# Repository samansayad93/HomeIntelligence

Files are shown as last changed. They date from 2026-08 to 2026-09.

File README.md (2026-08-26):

# intelligence — ESP32 Home Intelligence Hub

A Wi-Fi-connected, MQTT-integrated home automation and sensing node for the
**ESP32** (Arduino framework via PlatformIO). It reads a set of environmental
sensors, publishes them over MQTT, and can **capture and replay RF (433 & 315 MHz)
and infrared signals** — turning the board into a bridge between physical remotes,
sensors, and your smart-home broker.

On first boot it opens a captive setup portal, so no Wi-Fi or MQTT credentials are
hard-coded into the firmware.

---

## Table of Contents

- [Features](#features)
- [Hardware](#hardware)
- [Wiring](#wiring)
- [Software Architecture](#software-architecture)
- [Project Structure](#project-structure)
- [Getting Started](#getting-started)
- [First-Boot Provisioning](#first-boot-provisioning)
- [Configuration](#configuration)
- [Usage](#usage)
  - [Serial & MQTT Commands](#serial--mqtt-commands)
  - [MQTT Topics](#mqtt-topics)
- [Web Dashboard](#web-dashboard)
- [RF — Dual Band (433 & 315 MHz)](#rf--dual-band-433--315-mhz)
- [Persistent Storage](#persistent-storage)
- [Dependencies](#dependencies)
- [Known Issues & To-Do](#known-issues--to-do)

---

## Features

- **Provisioning portal** — configure Wi-Fi + MQTT from a phone/laptop on first
  boot; no rebuild required to change networks. The board runs in `WIFI_AP_STA`,
  so the `Intelligence-Setup` AP stays **always on** — you can connect to it at any
  time, even while the board is correctly joined to your router, and change the
  broker or Wi-Fi AP without erasing flash (see
  [First-Boot Provisioning](#first-boot-provisioning)).
- **MQTT telemetry** — publishes light, temperature, humidity, gas, and motion
  readings on a configurable base topic.
- **MQTT control** — the same commands available over Serial are accepted over an
  MQTT command topic.
- **Web dashboard** — a server-less browser dashboard (in [`Website/`](Website/))
  connects directly to the broker over WebSocket to show live telemetry and send
  the same commands (see [Web Dashboard](#web-dashboard)).
- **RF capture & replay** — record 433 *or* 315 MHz signals by name and replay
  them later. Both bands are handled simultaneously (see
  [RF — Dual Band](#rf--dual-band-433--315-mhz)).
- **IR capture & replay** — record infrared signals (NEC / SONY / SAMSUNG or raw)
  and replay them.
- **Local persistence** — all saved RF/IR signals and the provisioning profile are
  stored in LittleFS and survive reboots.
- **Status LED** — a heartbeat LED blinks (1 s on / 5 s off) while the firmware is
  running and gives a short 500 ms pulse whenever an RF/IR signal is captured or
  transmitted, giving at-a-glance feedback that the board is alive and acting.
- **Built-in alarm** — a buzzer that can be triggered manually, by gas threshold,
  or by motion.

## Hardware

**Board:** ESP32 DevKit (any common 38-pin variant). The full schematic and PCB
layout are checked into [`hardware/`](hardware/) (`Main.SchDoc` / `Main.pdf`
schematic, `PCB1.PcbDoc` board).

| Part | Purpose |
|---|---|
| DHT11 | Temperature & humidity |
| LDR (photoresistor) | Ambient light level |
| MQ-2 | Combustible gas / smoke |
| HC-SR505 (PIR) | Motion detection |
| Active buzzer | Alarm |
| Status LED | Heartbeat + capture/transmit pulse |
| 433 MHz TX + RX pair (e.g. FS1000A / XY-MK-5V) | 433 MHz RF |
| 315 MHz TX + RX pair | 315 MHz RF |
| IR receiver (e.g. TSOP38238) + IR LED | Infrared capture & transmit |

> The ESP32's ADC1 input-only pins (GPIO 34/35) are used for the analog sensors.

## Wiring

| Device | ESP32 GPIO | Notes |
|---|---|---|
| DHT11 data | **33** | 10 kΩ pull-up recommended |
| LDR (analog) | **34** | Input-only ADC1 pin |
| MQ-2 (analog AO) | **35** | Input-only ADC1 pin |
| PIR OUT | **13** | |
| Buzzer (+) | **32** | Active-low drive (LOW = on) |
| Status LED | **39** | Heartbeat + capture/transmit pulse |
| IR receiver DATA | **14** | |
| IR LED (transmit) | **25** | |
| 433 MHz RX DATA | **27** | |
| 433 MHz TX DATA | **26** | |
| 315 MHz RX DATA | **4** | *Adjustable — see config* |
| 315 MHz TX DATA | **5** | *Adjustable — see config* |

All modules share the ESP32's 3.3 V / 5 V and GND. Note that most 433/315 and IR
transmitter/receiver boards run at **5 V**; power them from `VCC` (5 V), and level-
shift the TX *data* lines (GPIO 26 / 5 / 25) if your module is not 5 V-tolerant.
Receiver DATA lines are safe to read directly.

---

## Software Architecture

The firmware is organized into independent modules, each with a header in
`include/<Module>/` and an implementation in `src/<Module>/`. A single `Sensors`
module orchestrates the others from `loop()`.

| Module | Responsibility |
|---|---|
| `main` | Setup/loop entry; routes MQTT commands to the serial handler |
| `Sensors` | Periodic sensor reads, RF/IR receive polling, alarm ticking |
| `Provisioning` | Always-on `WIFI_AP_STA` soft AP (`Intelligence-Setup`) + DNS hijack + web form to capture/change Wi-Fi/MQTT/device creds; reachable at any time, even while joined to the router |
| `MQTT` | Wi-Fi STA connect, PubSubClient connect/reconnect, publish/subscribe |
| `Serial` | Text command parser (shared by Serial and MQTT) + `help` |
| `RF` | Dual-band (433/315) RF capture & replay via RCSwitch |
| `IR` | Infrared capture & replay via IRremoteESP8266 |
| `Alarm` | Buzzer on/off + 2 s duty-cycle while alarming (active-low) |
| `LED` | Status LED heartbeat + capture/transmit pulse |
| `DHT`, `LDR`, `MQ2`, `PIR` | Individual sensor drivers |
| `Memory` | LittleFS JSON load/save for RF, IR, and provisioning data |
| `config` | Central pin map, MQTT topics, timing constants |

### Runtime loop

`setup()` → begins Serial → loads the saved provisioning profile → starts the
always-on config AP (`WIFI_AP_STA`) → sets up sensors + MQTT → prints help.

`loop()` → `handleSerial()` → `handleMQTT()` → `handleConfigAP()` → `handleSensors()`.

The board runs in `WIFI_AP_STA`: the station joins the provisioned router for MQTT
telemetry, while the `Intelligence-Setup` soft AP keeps broadcasting so the config
portal at `http://192.168.4.1` is reachable at any time — first boot or fully
provisioned and online alike. If Wi-Fi won't join, the station link is simply
retried; the AP (and thus re-provisioning) is always available regardless. A
broker-only outage (Wi-Fi up, broker down) does **not** affect the AP — it just keeps
retrying MQTT.

`handleSensors()` polls for an in-progress RF/IR capture, ticks the alarm buzzer,
ticks the status LED (heartbeat + any capture/transmit pulse), optionally checks
PIR motion, and every 10 s prints and publishes the sensor suite (LDR, temp,
humidity, PIR). MQ-2 is read on its own 10 s cadence after a 5 min warm-up.

## Project Structure

```
.
├── platformio.ini          # Build config, library deps, LittleFS filesystem
├── config.h (include/)     # Pins, topics, intervals (single source of truth)
├── include/                # Headers per module
│   └── <Module>/*.h
├── src/
│   ├── main.cpp
│   └── <Module>/*.cpp
├── lib/                    # (project-local libraries, currently empty)
├── hardware/               # Schematic (Main.SchDoc / Main.pdf) + PCB (PCB1.PcbDoc)
├── Website/                # Server-less browser dashboard (MQTT over WebSocket)
├── test/
└── note.md                 # Developer to-do / known-bugs scratchpad
```

---

## Getting Started

1. **Install PlatformIO**

   ```bash
   python -m pip install platformio
   ```

   (Or use the PlatformIO IDE extension for VS Code.)

2. **Build**

   ```bash
   pio run
   ```

3. **Upload to the board**

   ```bash
   pio run -t upload
   ```

4. **Open the serial monitor** (115200 baud)

   ```bash
   pio device monitor
   ```

> LittleFS is created/formatted automatically on first run — there is no `data/`
> folder to upload. The provisioning and signal files are written at runtime.

## First-Boot Provisioning

The board always boots in `WIFI_AP_STA` — it joins your router as a station (for
MQTT) **and** continuously broadcasts a setup access point:

| | |
|---|---|
| **SSID** | `Intelligence-Setup` |
| **Password** | `12345678` |
| **Setup URL** | `http://192.168.4.1` |

The AP runs a **captive portal**: it hijacks DNS and intercepts the OS
connectivity-check probes (iOS, Android, Windows), so connecting to the AP usually
pops the setup page automatically.

1. Connect to the `Intelligence-Setup` Wi-Fi network (the portal may open on its
   own).
2. Open `http://192.168.4.1` in a browser if it did not.
3. Fill in your Wi-Fi SSID/password, MQTT broker host/port (and optional user/
   pass), and a **Device** name. The device name becomes the per-device segment of
   every MQTT topic (see [MQTT Topics](#mqtt-topics)), so give each board a unique
   one. Then **Save & Restart**.
4. The board reboots, joins your Wi-Fi, and connects to the broker.

If no provisioning profile exists, the firmware falls back to the `WIFI_SSID` /
`MQTT_HOST` constants in `config.h` for the station link. To re-provision, you do
not need to erase flash or trigger a failure — see below.

### Re-provisioning while connected (always-on config AP)

The `Intelligence-Setup` AP stays **up even while the board is correctly joined to
your router**, so you can change the **MQTT broker** or the **Wi-Fi AP** at any time
without erasing flash, dropping the station link on purpose, or waiting for a
failure:

1. From any phone/laptop, connect to the `Intelligence-Setup` Wi-Fi network
   (`12345678`).
2. Open `http://192.168.4.1` in a browser (the captive portal may open on its own).
3. The form is **prefilled** with the current SSID, broker host/port, username,
   and device name, so you can edit just the field you want to change. Password
   fields are left blank on purpose (they are not echoed back); **leave them blank
   to keep the current password**, or type a new one to replace it.
4. **Save & Restart** — the board writes the new profile and reboots into it.

Because the board keeps its station link up during normal operation, you can also
still reach it over your normal LAN at its station IP for MQTT/dashboard traffic;
only configuration changes go through the `Intelligence-Setup` AP.

## Configuration

All tunables live in [`include/config.h`](include/config.h):

- **Pins** — the wiring table above.
- **MQTT** — `MQTT_BASE_TOPIC` (`homeintelligence`), broker host/port, client ID
  (`esp32-intelligence`, used as the per-device topic segment when no device name is
  provisioned), credentials (used only as a fallback; the portal overrides them).
- **Timing** — sensor interval (10 s), MQ-2 preheat (5 min), MQ-2 threshold (700),
  buzzer duty cycle (2 s), MQTT reconnect interval (1 s), status LED heartbeat
  (1 s on / 5 s off, 500 ms pulse).

---

## Usage

The same text commands work two ways:
- typed into the **Serial monitor** at 115200, or
- published to the **MQTT command topic** `<base>/<device>/command`, e.g.
  `homeintelligence/esp32-intelligence/command` (see [MQTT Topics](#mqtt-topics)).

### Serial & MQTT Commands

| Command | Action |
|---|---|
| `rf rx <name>` | Wait for an RF signal (433 **or** 315) and save it as `<name>` |
| `rf tx <name>` | Transmit the RF signal saved as `<name>` (on its original band) |
| `rf list` | List saved RF signals (name, band, code, bits, protocol, pulse) — printed to Serial **and** published to `…/RF/list` |
| `rf del <name>` | Delete the RF signal saved as `<name>` |
| `ir rx <name>` | Wait for an IR signal and save it as `<name>` |
| `ir tx <name>` | Transmit the IR signal saved as `<name>` |
| `ir list` | List saved IR signals — printed to Serial **and** published to `…/IR/list` |
| `ir del <name>` | Delete the IR signal saved as `<name>` |
| `buzzer on` / `buzzer off` | Start / stop the alarm buzzer |
| `motion on` / `motion off` | Start / stop the motion detection |
| `help` | Print the command list |

**Examples**

```
rf rx living_room_light      # press your 433/315 remote; it's captured + saved
rf tx living_room_light      # replay it later (correct band chosen automatically)
ir rx tv_power
ir tx tv_power
rf del living_room_light   # remove a saved RF signal
buzzer off
```

### MQTT Topics

All topics are namespaced per device: `<base>/<device>/<subtopic>`, where `<base>`
is `MQTT_BASE_TOPIC` (`homeintelligence`) and `<device>` is the name set in the
provisioning portal (or `MQTT_CLIENT_ID`, `esp32-intelligence`, as a fallback). The
examples below use `homeintelligence/esp32-intelligence`.

Published to:

| Topic | Payload | Trigger |
|---|---|---|
| `…/sensor/LDR` | light reading | every 10 s |
| `…/sensor/TEMP` | °C | every 10 s |
| `…/sensor/HUM` | % humidity | every 10 s |
| `…/sensor/PIR` | `0`/`1` | every 10 s |
| `…/sensor/MQ2` | gas reading | every 10 s (after warm-up) |
| `…/alarm` | `MQ2 threshold exceeded!` / `Motion Detected!` | when an incident occurs (also starts the buzzer) |
| `…/alarm` | `Motion Detection: ON` / `Motion Detection: OFF` | when motion detection is armed/disarmed (retained) |
| `…/RF/list` | JSON per saved RF signal (`name`, `code`, `bits`, `protocol`, `pulse`, `band`) | on `rf list` |
| `…/IR/list` | JSON per saved IR signal (`name`, `protocol`, `value`, `bits`) | on `ir list` |

(`…` = `homeintelligence/<device>`.)

Subscribed to:

| Topic | Payload |
|---|---|
| `…/command` | any command from the table above |

So to toggle the buzzer from your broker, publish `buzzer on` to
`homeintelligence/esp32-intelligence/command`.

---

## Web Dashboard

A self-contained, server-less dashboard lives in [`Website/`](Website/). It connects
**directly from the browser to your MQTT broker over WebSocket** (no backend, no
build step) to render live sensor cards with sparklines, an alarm banner, and a set
of control buttons that publish the same commands as Serial.

```
┌────────────┐   WebSocket (ws/wss)   ┌──────────────┐   TCP 1883   ┌────────────┐
│  Browser   │ ─────────────────────▶ │  MQTT broker │ ───────────▶ │   ESP32    │
│  dashboard │ ◀───────────────────── │  (Mosquitto) │ ◀─────────── │  (firmware)│
└────────────┘   sensor/+alarm  (sub) └──────────────┘  command (pub)└────────────┘
```

Because browsers cannot speak raw MQTT/TCP, your broker must expose a **WebSocket
listener** (e.g. Mosquitto `listener 9001` + `protocol websockets`). The dashboard
subscribes to `<base>/<device>/sensor/#` and `<base>/<device>/alarm`, and publishes
to `<base>/<device>/command` — set the same `<device>` you provisioned.

Quick start:

```bash
cd Website
python3 -m http.server 8080      # then open http://localhost:8080
```

Full setup, options, and troubleshooting are in [`Website/README.md`](Website/README.md).

---

## RF — Dual Band (433 & 315 MHz)

RF supports **both 433 MHz and 315 MHz simultaneously**. Because a receiver module
is frequency-specific (a 433 module cannot decode a 315 MHz signal and vice-versa),
the firmware drives **two independent `RCSwitch` instances** — one per band — each
on its own RX/TX pin pair:

| Band | RX pin | TX pin |
|---|---|---|
| 433 MHz | GPIO 27 | GPIO 26 |
| 315 MHz | GPIO 4 | GPIO 5 |

- **Capture:** `rf rx <name>` listens on *both* receivers; whichever band actually
  receives the signal is recorded. The console confirms the band, e.g.
  `Saved RF signal: living_room_light (433 MHz)`.
- **Replay:** `rf tx <name>` automatically uses the band that signal was captured
  on — no need to specify it.

Each saved signal stores `code`, `bits`, `protocol`, `pulse`, and `band`, so it is
always replayed faithfully on the right hardware. If the default 315 pins (4/5)
clash with your board, change `RF_RX_315_PIN` / `RF_TX_315_PIN` in
[`config.h`](include/config.h).

---

## Persistent Storage

LittleFS holds three JSON files (created on demand):

| File | Contents |
|---|---|
| `/provisioning.json` | Wi-Fi + MQTT credentials from the portal |
| `/rf_signals.json` | Saved RF signals (up to 20) |
| `/ir_signals.json` | Saved IR signals (up to 20, raw buffer up to 200 samples) |

Old RF captures saved before dual-band support are loaded with a default band of
**433 MHz**, so existing recordings keep working.

## Dependencies

Declared in [`platformio.ini`](platformio.ini):

- `adafruit/DHT sensor library` + `adafruit/Adafruit Unified Sensor` — DHT11
- `sui77/rc-switch` — 433/315 MHz RF
- `crankyoldgit/IRremoteESP8266` — IR send/receive
- `bblanchon/ArduinoJson` — JSON config & signal storage
- `knolleary/PubSubClient` — MQTT client

PlatformIO installs these automatically on first build.

---

## Known Issues & To-Do

Tracked in [`note.md`](note.md):

- **IR TX does not currently work** (RX is functional).
- Make the web dashboard multi-page.

---

*No license has been set for this project. Add one before sharing or deploying.*

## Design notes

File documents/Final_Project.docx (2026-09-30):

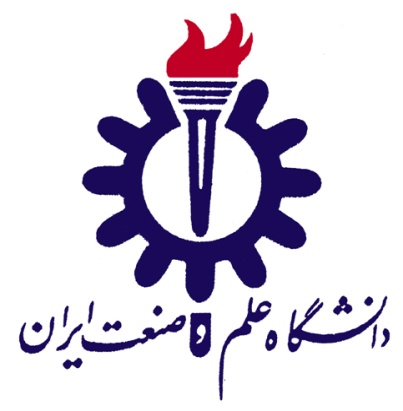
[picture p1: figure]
IUST

دانشكده مهندسی کامپیوتر

پروژه پایانی کارشناسی

عنوان پروژه:

طراحی و پیاده سازی سامانه هوشمند تشخیص دود و کنترل تجهیزات خانگی مبتی بر ESP32

نگارنده:

سامان صیاد فعال

۴۰۱۵۲۱۴۰۸

استاد راهنما:

دكتر امیر مهدی حسینی منزه

شهریور ماه ۱۴۰۵

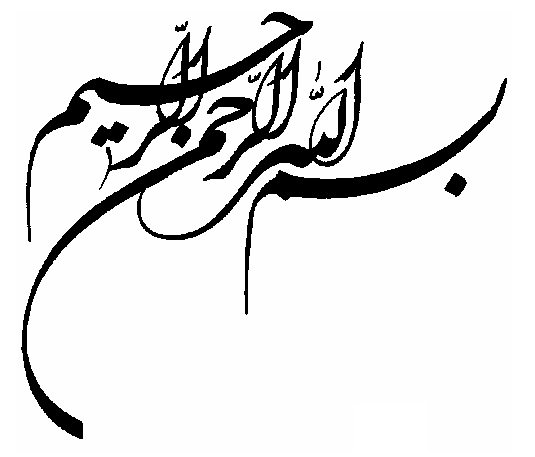
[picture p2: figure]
␂矸曰矷淀矵ح矨

چکيده

در این پروژه، یک سامانه هوشمند مبتنی بر برد ESP32 با هدف طراحی و پیاده سازی یک واحد یکپارچه برای پایش شرایط محیطی، تشخیص شرایط خطر و کنترل تجهیزات الکترونیکی توسعه داده شده است. هدف اصلی سامانه، فراهم کردن امکان دریافت و پردازش اطلاعات محیطی و انتقال آنها به یک سامانه نرم افزاری از طریق شبکه بی‌سیم، در کنار ایجاد قابلیت کنترل و ارسال فرمان به برخی تجهیزات الکترونیکی موجود در محیط است. به منظور پایش وضعیت محیط، دستگاه به مجموعه ای از حسگرها شامل حسگر گاز MQ-2، حسگر دما و رطوبت DHT11، حسگر شدت نور LDR و حسگر تشخیص حرکت PIR مجهز شده است. حسگر MQ-2 با استفاده از خروجی آنالوگ، امکان اندازه گیری سطح نسبی گاز و دود موجود در محیط را فراهم می کند و در صورت عبور مقدار اندازه گیری شده از آستانه تعیین شده، شرایط به عنوان وضعیت هشدار شناسایی شده و سامانه اقدام به فعال سازی هشدار صوتی می کند. همچنین اطلاعات مربوط به دما، رطوبت، شدت نور و وضعیت حرکت در بازه های زمانی مشخص از محیط دریافت شده و برای پایش و نمایش وضعیت سیستم در اختیار سامانه نرم افزاری قرار می گیرد. به منظور افزایش قابلیت کاربردی دستگاه در حوزه کنترل تجهیزات، دو بستر ارتباطی رادیویی RF در فرکانس های ۳۱۵ و ۴۳۳ مگاهرتز و همچنین ارتباط مادون قرمز IR در سامانه در نظر گرفته شده است. این بخش امکان دریافت و شناسایی فرمان های رادیویی و مادون قرمز، ذخیره سازی آنها و استفاده مجدد از فرمان های ذخیره شده برای کنترل تجهیزات سازگار را فراهم می کند. ارتباط دستگاه با شبکه از طریق قابلیت WiFi برد ESP32 برقرار شده و به منظور انتقال داده و فرمان میان دستگاه و سامانه نرم افزاری از پروتکل MQTT استفاده شده است. همچنین برای ساده سازی راه اندازی اولیه و جلوگیری از وابستگی به اطلاعات شبکه ثابت، یک سازوکار provisioning در دستگاه پیاده سازی شده است که از طریق یک نقطه دسترسی بی‌سیم و درگاه پیکربندی تحت وب، امکان تنظیم مشخصات شبکه WiFi، اطلاعات MQTT Broker را فراهم می کند. در بخش نرم افزاری کاربر نیز یک داشبورد تحت وب برای نمایش داده های دریافت شده از دستگاه و ارسال فرمان های کنترلی طراحی شده است. به این ترتیب، کاربر می تواند بدون نیاز به دسترسی مستقیم به سخت افزار، وضعیت محیط را پایش کرده، شرایط هشدار را مشاهده نموده و فرمان های مورد نیاز را برای تجهیزات ارسال کند. این سامانه می تواند به عنوان یک نمونه پایه برای توسعه راهکار های هوشمند سازی محیط های مسکونی و اداری، سامانه های پایش محیطی و سیستم های کنترل تجهیزات مورد استفاده قرار گیرد.

واژه‌هاي كليدي: خانه هوشمند، اتوماسیون خانگی، ESP32، اینترنت اشیا (IoT)

# فصل 1: مقدمه

در سال‌های اخیر، توسعه فناوری‌های ارتباطی و سامانه های نهفته موجب گسترش استفاده از سیستم‌های هوشمند در محیط‌های مسکونی، اداری و صنعتی شده است. یکی از مهم‌ترین حوزه‌های حاصل از این توسعه، اینترنت اشیا (Internet of Things یا IoT) است. اینترنت اشیا به شبکه ای از تجهیزات فیزیکی اطلاق می‌شود که با بهره‌گیری از حسگرها، پردازنده ها، نرم‌افزارها و واسط های ارتباطی، قابلیت جمع آوری، پردازش، تبادل اطلاعات و در برخی موارد اعمال کنترل بر محیط پیرامون خود را دارند [1].در چنین سامانه هایی، حسگرها وظیفه دریافت اطلاعات از محیط، واحد پردازشی وظیفه تحلیل و مدیریت داده ها و بخش ارتباطی وظیفه انتقال اطلاعات و دریافت فرمان های کنترلی را بر عهده دارد [1] [2].

یکی از کاربردهای مهم اینترنت اشیا، توسعه سامانه های هوشمند خانگی است. در یک محیط هوشمند، تجهیزات مختلف می‌توانند از طریق یک شبکه ارتباطی با یکدیگر و با کاربر تعامل داشته باشند. این تعامل می تواند شامل پایش شرایط محیطی، تشخیص رخداد های غیرعادی، ارسال هشدار، کنترل تجهیزات الکتریکی و ثبت اطلاعات باشد. استفاده از چنین سامانه هایی می تواند امکان نظارت از راه دور و کاهش وابستگی به کنترل دستی تجهیزات را فراهم کند.

در این پروژه، یک هاب هوشمند مبتنی بر برد ESP32 طراحی و پیاده سازی شده است. ESP32 یک سامانه روی تراشه با قابلیت WiFi در باند ۲.۴ گیگاهرتز، پردازنده ۳۲ بیتی و مجموعه‌ای از واسط های ورودی/خروجی دیجیتال و آنالوگ است که توسط شرکت Espressif ارائه شده و برای کاربردهایی از جمله تجهیزات هوشمند خانگی و اینترنت اشیا مناسب است [3]. این ویژگی ها باعث شده است ESP32 بتواند علاوه بر پردازش داده های حسگرها، ارتباط شبکه ای و کنترل تجهیزات جانبی را نیز در یک واحد سخت افزاری انجام دهد.

سیستم توسعه یافته در این پروژه علاوه بر تشخیص دود و گاز، امکان اندازه گیری دما، رطوبت و شدت نور و همچنین تشخیص حرکت را فراهم می‌کند. همچنین برای افزایش قابلیت کنترل تجهیزات مختلف، دو مجموعه ارتباط رادیویی در فرکانس های ۳۱۵ و ۴۳۳ مگاهرتز و یک مجموعه ارتباط مادون قرمز در نظر گرفته شده است. به این ترتیب، سیستم قادر است برخی سیگنال های رادیویی و مادون قرمز را دریافت، ذخیره و در صورت نیاز بازپخش کند.

ارتباط میان هاب هوشمند و زیرساخت نرم‌افزاری سیستم از طریق WiFi و پروتکل MQTT انجام می‌شود. MQTT یک پروتکل ارتباطی سبک مبتنی بر الگوی انتشار/اشتراک (Publish/Subscribe) است که به طور ویژه برای محیط‌های دارای محدودیت منابع و کاربردهای ماشین به ماشین و اینترنت اشیا مناسب طراحی شده است [4]. در این پروژه، داده های حسگرها از طریق MQTT منتشر شده و فرمان های کنترلی نیز از طریق همین بستر به ESP32 ارسال می‌شوند.

از سوی دیگر، برای تعامل کاربر با سیستم، یک داشبورد تحت وب طراحی شده است که از طریق WebSocket به MQTT Broker متصل می‌شود. این داشبورد امکان مشاهده اطلاعات حسگرها، مشاهده هشدارها و ارسال فرمان های کنترلی را فراهم می‌کند. در نتیجه، پروژه حاضر را می‌توان یک هاب هوشمند چند منظوره دانست که وظایف پایش محیط، تشخیص رخداد، ایجاد هشدار، ارتباط شبکه ای و کنترل تجهیزات را در یک سامانه یکپارچه انجام می‌دهد.

## 1-1- بیان مسئله

در بسیاری از محیط‌های مسکونی و اداری، تجهیزات الکتریکی و سامانه های مختلف به صورت مستقل مورد استفاده قرار می گیرند و اطلاعات مربوط به شرایط محیطی نیز معمولاً به صورت متمرکز و مستمر جمع آوری نمی شود. در روش های سنتی، تشخیص رخدادهایی مانند افزایش میزان دود یا گاز، تغییرات دما، حضور افراد یا تغییر شدید شرایط نوری ممکن است به صورت دستی یا توسط تجهیزات مستقل انجام شود. چنین رویکردی علاوه بر افزایش پیچیدگی سیستم، امکان پایش یکپارچه و کنترل از راه دور را محدود می‌کند.

از طرف دیگر، بسیاری از تجهیزات موجود در محیط‌های خانگی از روش های ارتباطی متفاوتی برای کنترل استفاده می‌کنند. برخی تجهیزات از ریموت های مادون قرمز و برخی دیگر از ریموت های رادیویی در فرکانس هایی مانند ۳۱۵ یا ۴۳۳ مگاهرتز استفاده می‌کنند. در نتیجه، برای کنترل یکپارچه این تجهیزات معمولاً نیاز به چندین کنترل کننده و واسط مجزا وجود دارد.

مسئله اصلی این پروژه، طراحی و پیاده‌سازی یک سامانه یکپارچه است که بتواند اطلاعات مربوط به شرایط محیط را از طریق مجموعه‌ای از حسگرها دریافت کرده، آنها را در یک واحد پردازشی مدیریت کند، اطلاعات را از طریق شبکه WiFi و MQTT در اختیار نرم‌افزار قرار دهد و امکان کنترل تجهیزات الکتریکی را نیز فراهم کند.

برای دستیابی به این هدف، از ESP32 به عنوان هسته پردازشی و ارتباطی سیستم استفاده شده است.

در بخش پایش محیط، سنسور MQ-2 برای تشخیص دود و گازهای قابل اشتعال، سنسور DHT11 برای اندازه گیری دما و رطوبت، حسگر نوری LDR برای اندازه گیری نسبی شدت نور و حسگر حرکتی PIR برای تشخیص حرکت مورد استفاده قرار گرفته اند. اطلاعات به دست آمده از این حسگرها به صورت دوره‌ای پردازش و از طریق MQTT منتشر می‌شوند.

در بخش کنترل نیز سیستم از گیرنده و فرستنده های RF در دو باند ۳۱۵ و ۴۳۳ مگاهرتز و همچنین گیرنده و فرستنده مادون قرمز استفاده می‌کند. کتابخانه RCSwitch امکان دریافت و ارسال کدهای برخی تجهیزات رادیویی رایج در فرکانس های ۳۱۵ و ۴۳۳ مگاهرتز را فراهم می‌کند [5]. همچنین کتابخانه IRremoteESP8266 برای دریافت و ارسال سیگنال های مادون قرمز مورد استفاده قرار گرفته است [6].

بنابراین، مسئله این پروژه را می‌توان به صورت طراحی یک هاب هوشمند تعریف کرد که سه وظیفه اصلی پایش شرایط محیطی، تشخیص رخداد و ایجاد هشدار و کنترل تجهیزات الکتریکی را در یک بستر واحد ترکیب می‌کند.

## 1-2- اهمیت و ضرورت پروژه

افزایش استفاده از تجهیزات الکتریکی و گسترش سیستم های هوشمند، نیاز به سامانه هایی را افزایش داده است که بتواند علاوه بر کنترل تجهیزات، وضعیت محیط را نیز پایش کنند. یکی از مزیت های اصلی استفاده از اینترنت اشیا در چنین سامانه هایی، ایجاد ارتباط میان دنیای فیزیکی و سامانه های نرم افزاری است؛ به گونه ای که اطلاعات حسگر ها می توانند دریافت، منتقل و در بخش نرم افزاری پردازش شوند.

وجود چندین حسگر در یک سامانه امکان جمع آوری همزمان اطلاعات مختلف محیطی را فراهم می‌کند. در پروژه حاضر، اطلاعات مربوط به دما، رطوبت، شدت نور، میزان دود و وضعیت حرکت در اختیار سیستم قرار می گیرد. این اطلاعات می‌توانند برای بررسی وضعیت لحظه ای محیط و تشخیص برخی شرایط غیرعادی مورد استفاده قرار گیرند.

استفاده از سنسور های محیطی امکان واکنش سریع تر سیستم نسبت به رخدادهایی مانند افزایش مقدار گاز یا دود و تشخیص حرکت را فراهم می‌کند. در پروژه حاضر، در صورت عبور مقدار خوانده شده از سنسور MQ-2 از آستانه تعیین شده، سیستم وضعیت هشدار را فعال کرده و پیام مربوطه را از طریق MQTT منتشر می‌کند. همچنین در صورت تشخیص حرکت، امکان ایجاد هشدار و فعال سازی بازر وجود دارد.

ارتباط WiFi و MQTT باعث می‌شود اطلاعات جمع آوری شده تنها در سطح خود دستگاه باقی نماند و بتوان آنها را به یک Broker و نرم‌افزارهای دیگر منتقل کرد. MQTT به دلیل استفاده از مدل Publish/Subscribe، امکان جداسازی تولیدکننده و مصرف کننده داده را فراهم می‌کند و برای ارتباط میان تجهیزات IoT مناسب است [4].

یکی از ویژگی های مهم پروژه، ترکیب پایش محیط با کنترل تجهیزات الکتریکی است. سیستم می تواند سیگنال های RF در دو باند ۳۱۵ و ۴۳۳ مگاهرتز را دریافت و ذخیره کرده و در زمان مناسب بازپخش کند. کتابخانه RCSwitch نیز برای کنترل تجهیزات رادیویی رایج با فرستنده ها و گیرنده های ۳۱۵ و ۴۳۳ مگاهرتز طراحی شده است [5]. همچنین استفاده از ارتباط مادون قرمز باعث می‌شود سیستم بتواند با برخی تجهیزات مجهز به ریموت IR تعامل داشته باشد. کتابخانه IRremoteESP8266 برای ESP32 امکان دریافت و ارسال سیگنال های مادون قرمز و پشتیبانی از پروتکل های متعدد را فراهم می‌کند [6].

ترکیب چندین قابلیت در یک برد ESP32 باعث می‌شود به جای استفاده از چند سیستم مستقل برای پایش محیط، دریافت فرمان های بی‌سیم و کنترل تجهیزات، بتوان بخش قابل توجهی از این وظایف را در یک هاب واحد پیاده‌سازی کرد. همچنین معماری ماژولار نرم‌افزار، استفاده از MQTT و قابلیت های ارتباطی ESP32 امکان توسعه سیستم در آینده را فراهم می‌کند. برای مثال، می‌توان حسگرهای جدید، تجهیزات کنترلی بیشتر یا سرویس های نرم افزاری دیگر را بدون تغییر اساسی در ساختار کلی سیستم به آن اضافه کرد.

## 1-3- اهداف پروژه

هدف اصلی این پروژه، طراحی و پیاده سازی یک سامانه هوشمند مبتنی بر ESP32 برای تشخیص دود و آتش و پایش محیط و کنترل تجهیزات الکتریکی از طریق شبکه WiFi است و همچنین اهداف فرعی پروژه عبارت‌اند از:

1. طراحی و پیاده سازی بخش سخت افزاری مبتنی بر ESP32
2. تشخیص وجود دود و شرایط مرتبط با آتش با استفاده از MQ-2
3. اندازه گیری دما و رطوبت محیط با استفاده از DHT11
4. اندازه گیری شدت نور محیط با استفاده از LDR
5. تشخیص حضور یا حرکت در محیط با استفاده از حسگر PIR
6. ایجاد سیستم هشدار صوتی با استفاده از بازر
7. دریافت سیگنال های مادون قرمز از کنترلر تجهیزات مختلف
8. ذخیره فرمان های مادون قرمز دریافت شده
9. ارسال سیگنال های مادون قرمز برای کنترل تجهیزات مختلف
10. دریافت و ارسال سیگنال های رادیویی برای کنترل تجهیزات رادیویی
11. برقراری ارتباط دستگاه با شبکه WiFi
12. استفاده از MQTT برای تبادل اطلاعات میان دستگاه و سامانه نرم افزاری
13. ایجاد قابلیت پایش سیستم از راه دور
14. فراهم کردن امکان کنترل تجهیزات الکتریکی از طریق سامانه نرم افزاری
15. ایجاد ساختاری قابل توسعه برای اضافه کردن حسگرها و قابلیت های جدید در آینده

## 1-4- محدوده پروژه

محدوده این پروژه شامل طراحی و پیاده سازی یک نمونه عملیاتی از سامانه هوشمند پایش و کنترل محیط مبتنی بر ESP32 است. در این پروژه، ESP32 به عنوان واحد پردازش مرکزی وظیفه دریافت اطلاعات از حسگرها، پردازش داده ها، مدیریت ارتباطات و ارسال یا دریافت سیگنال های مادون قرمز و رادیویی را بر عهده دارد.

- تشخیص دود و شرایط مرتبط با آتش
- اندازه گیری دما و رطوبت و شدت نور
- تشخیص حرکت
- ارسال و دریافت سیگنال های مادون قرمز
- ارسال و دریافت سیگنال های رادیویی
- اتصال دستگاه به WiFi
- ارتباط با سامانه نرم افزاری
- ارسال اطلاعات حسگرها به سامانه نرم افزاری
- دریافت فرمان از سامانه نرم افزاری برای کنترل تجهیرات الکتریکی

با وجود قابلیت های فوق، پروژه دارای محدوده مشخصی است. برای مثال، عملکرد تشخیص آتش در این پروژه در سطح یک سامانه نمونه و آموزشی/مهندسی در نظر گرفته شده و نباید آن را به عنوان جایگزین تجهیزات ایمنی و اعلام حریق دارای تاییدیه استاندارد برای کاربرد های حیاتی در نظر گرفت. همچنین کنترل تجهیزات از طریق IR و RF به نوع پروتکل و سازگاری تجهیزات مقصد وابسته است.

## 1-5- روش انجام پروژه

فرایند انجام پروژه به صورت مرحله ای و بر اساس نیازمندی های سخت افزاری و نرم افزاری سیستم انجام شده است. در مرحله نخست، مسئله و نیازمندی های اصلی سیستم شامل تشخیص شرایط خطر، پایش محیط و کنترل تجهیزات الکتریکی بررسی شد. سپس معماری کلی سیستم و نحوه ارتباط میان حسگرها، ESP32 و سامانه نرم افزاری مشخص گردید. در مرحله بعد، قطعات سخت افزاری موردنیاز انتخاب و مدار اولیه طراحی شد. ESP32 به عنوان کنترل کننده مرکزی انتخاب شد؛ زیرا علاوه بر قابلیت پردازشی، امکانات ارتباطی موردنیاز پروژه از جمله WiFi را در اختیار قرار می دهد. پس از طراحی سخت افزار، Firmware دستگاه توسعه داده شد. این بخش وظیفه خواندن اطلاعات حسگرها، تشخیص وضعیت های مختلف، مدیریت ورودی و خروجی ها، دریافت و ارسال سیگنال های IR و RF و همچنین مدیریت ارتباط شبکه را بر عهده دارد. در بخش ارتباطی، دستگاه از طریق WiFi به شبکه متصل شده و ارتباط میان ESP32 و سامانه نرم افزاری با استفاده از MQTT برقرار شده است. در این معماری، دستگاه می تواند اطلاعات مربوط به حسگرها و وضعیت خود را در Topic های مشخص منتشر کند و در مقابل، پیام های کنترلی را از Topic های مربوطه دریافت نماید. در ادامه بخش نرم افزاری توسعه داده شده و قابلیت مشاهده اطلاعات و ارسال فرمان های کنترلی در آن فراهم شده است. پس از اتصال اجزای مختلف، آزمایش های مربوط به حسگرها، ارتباط WiFi، تبادل پیام MQTT و عملکرد فرستنده و گیرنده های IR و RF انجام شده است. در نهایت، عملکرد کلی سامانه با بررسی سناریو های مختلف مورد ارزیابی قرار گرفته است.

# فصل 2: مبانی نظری

گسترش فناوری های ارتباطی، میکروکنترلر های کم مصرف و شبکه های بی‌سیم باعث شده است که تجهیزات الکترونیکی بتوانند علاوه بر انجام وظایف کنترلی، اطلاعات محیط پیرامون خود را نیز دریافت و از طریق شبکه منتقل کنند. این رویکرد یکی از پایه های اصلی شکل گیری اینترنت اشیا (Internet of Things یا IoT) است.

در سامانه های هوشمند، ترکیب حسگر ها، واحد پردازش، ارتباط شبکه و نرم افزار کاربردی امکان پایش شرایط محیطی و کنترل تجهیزات را فراهم می کند. در یک خانه هوشمند، چنین سامانه ای می تواند اطلاعاتی مانند دما، رطوبت، شدت نور، وجود دود یا آتش را دریافت کرده و در مقابل، تجهیزات مختلف را از طریق ارتباطات بی‌سیم کنترل کند.

پروژه حاضر یک سیستم هوشمند مبتنی بر ESP32 است که علاوه بر پایش شرایط محیطی، قابلیت تشخیص دود و آتش، تشخیص حرکت، ایجاد هشدار صوتی و دریافت و ارسال فرمان های مادون قرمز و رادیویی را فراهم می کند. ارتباط دستگاه با زیرساخت شبکه از طریق WiFi و تبادل داده با استفاده از پروتکل MQTT انجام می شود.

## 2-1- اینترنت اشیا

اینترنت اشیا به مجموعه‌ای از تجهیزات فیزیکی گفته می‌شود که دارای حسگر، قابلیت پردازش و ارتباط شبکه بوده و می‌توانند اطلاعات مربوط به محیط یا وضعیت خود را جمع آوری و با سایر سامانه ها مبادله کنند [1]. در یک سامانه IoT معمولاً سه وظیفه اصلی دریافت اطلاعات از محیط، پردازش و تفسیر اطلاعات، ارسال اطلاعات یا اجرای فرمان وجود دارد. در پروژه حاضر، حسگرهای MQ-2، DHT11،LDR و PIR وظیفه دریافت اطلاعات محیطی را بر عهده دارند.ESP32 وظیفه پردازش اولیه را انجام داده و WiFi و MQTT برای انتقال اطلاعات به کار می روند.

### 2-1-1- اجزای اصلی یک سامانه IoT

یک سامانه اینترنت اشیا از مجموعه ای از اجزای سخت افزاری و نرم افزاری تشکیل می شود که وظیفه دریافت اطلاعات از محیط، پردازش داده ها، برقراری ارتباط و ارائه خدمات به کاربر را بر عهده دارند. معمولا می توان عملکرد کلی آنها را در چهار بخش اصلی شامل لایه حسگر، لایه پردازش، لایه ارتباطی و لایه کاربرد بررسی کرد. در این ساختار، داده ابتدا از محیط دریافت می شود، سپس توسط واحد پردازشی مورد پردازش قرار گرفته و از طریق بستر ارتباطی به سایر اجزای سامانه منتقل می شود. در نهایت، داده های پردازش شده در اختیار کاربر یا سایر سرویس های کاربردی قرار گرفته و امکان انجام عملیات کنترلی نیز فراهم می شود.

      2-1-1-1- لایه حسگر

لایه حسگر نخستین بخش سامانه IoT است که مستقیما با محیط فیزیکی ارتباط دارد. وظیفه اصلی این لایه، دریافت کمیت ها و رخداد های فیزیکی موجود در محیط و تبدیل آنها به داده ای است که واحد پردازشی بتواند آن را دریافت و تحلیل کند. کمیت هایی مانند دما، رطوبت، شدت نور، وجود دود یا گاز و حرکت افراد از جمله اطلاعاتی هستند که می توانند توسط حسگر های مختلف اندازه گیری شوند. نوع حسگر های مورد استفاده در این لایه به کاربرد سامانه بستگی دارد و معمولا برای پوشش داده چندین جنبه از وضعیت محیط، از مجموعه ای از حسگر ها به صورت هم زمان استفاده می شود.

      2-1-1-2- لایه پردازش

لایه پردازش وظیفه دریافت داده های حاصل از لایه حسگر، مدیریت آنها و اجرای منطق کنترلی سامانه را بر عهده دارد. این لایه در واقع هسته تصمیم گیری سامانه IoT محسوب می شود و می تواند عملیاتی مانند خواندن دوره ای حسگر ها، بررسی شرایط خاص، تشخیص رخداد ها، مدیریت هشدارها و آماده سازی داده ها برای انتقال به شبکه را انجام دهد. در سامانه های مبتنی بر میکروکنترلر، این وظایف معمولا توسط یک برد پردازشی انجام می شود که علاوه بر قدرت پردازشی، رابط های ورودی و خروجی و امکانات ارتباطی مورد نیاز را در اختیار سیستم قرار می دهد.

      2-1-1-3- لایه ارتباطی

لایه ارتباطی مسئول ایجاد ارتباط میان تجهیزات، واحد پردازشی و سرویس های نرم افزاری است. در یک سامانه IoT، داده های تولید شده توسط حسگرها زمانی ارزش کاربردی بیشتری پیدا می کنند که بتوان آنها را از طریق یک شبکه به سایر بخش های سیستم منتقل کرد. همچنین این لایه باید امکان انتقال اطلاعات در جهت معکوس، یعنی از سایر بخش های سیستم به دستگاه را نیز فراهم کند. انتخاب فناوری و پروتکل ارتباطی مناسب تاثیر مستقیمی بر نحوه عملکرد و توسعه پذیری سامانه IoT دارد.

      2-1-1-4- لایه کاربرد

لایه کاربرد بالاترین سطح معماری سامانه IoT است و وظیفه آن تبدیل داده ها و قابلیت های لایه های پایین تر به خدمات قابل استفاده برای کاربر است. در این لایه، اطلاعات دریافت شده از تجهیزات و حسگر ها می توانند به شکل مناسب به کاربر نمایش داده شوند و در مقابل، فرمان های مورد نظر کاربر نیز از طریق رابط کاربری به سامانه ارسال شوند. در واقع این لایه نقطه تعامل مستقیم کاربر با سامانه محسوب می شود و باید بتواند وضعیت سیستم را به شکلی قابل فهم ارائه کند.

### 2-1-2- کاربرد اینترنت اشیا در خانه هوشمند

خانه هوشمند یکی از مهم ترین حوزه های کاربرد اینترنت اشیا است. در یک سامانه خانه هوشمند، تجهیزات و حسگر های مختلف از طریق یک شبکه ارتباطی به یکدیگر متصل می شوند و امکان جمع آوری اطلاعات، پایش وضعیت و کنترل تجهیزات فراهم می شود. این تجهیزات می تواند شامل حسگر های محیطی، سیستم های هشدار، تجهیزات روشنایی، لوازم خانگی و سایر تجهیزات الکترونیکی باشند. اتصال این اجزا به یک سامانه مرکزی یا بستر نرم افزاری باعث می شود اطلاعات محیطی در یک محل قابل مشاهده بوده و بسیاری از عملیات کنترلی بدون نیاز به حضور فیزیکی کاربر انجام شوند.

## 2-2- سیستم های خانه هوشمند

خانه هوشمند به محیطی اطلاق می شود که در آن تجهیزات و سامانه های مختلف با استفاده از فناوری های ارتباطی و پردازشی به یکدیگر متصل شده و امکان پایش، مدیریت و کنترل تجهیزات و شرایط محیطی به صورت خودکار یا از راه دود فراهم می شود. در چنین سامانه هایی، اطلاعات محیط توسط حسگر های مختلف جمع آوری شده و پس از پردازش، از طریق یک بستر ارتباطی به بخش نرم افزاری منتقل می شوند. در مقابل، کاربر نیز می تواند با ارسال فرمان های کنترلی، عملکرد تجهیزات متصل به سامانه را تغییر دهد. فناوری هایی مانند Zigbee، Bluetooth، WiFi و Z-Wave از جمله فناوری های مورد استفاده در پیاده سازی سامانه های خانه هوشمند هستند.

## 2-3- میکروکنترلر ESP32

ESP32 خانواده ای از تراشه های سیستم روی تراشه (SoC[^1]) شرکت Espressif Systems است که برای کاربرد های ارتباطی و سیستم های نهفته طراحی شده است. این خانواده دارای پردازنده ۳۲ بیتی، حافظه، WiFi، ADC، Bluetooth و مجموعه ای از رابط های جانبی است. طبق مستندات رسمی، ESP32 از WiFi با استاندارد های 802.11b/g/n پشتیبانی کرده و دارای ADC دوازده بیتی، GPIO های متعدد، PWM، I2C، SPI و سایر واحد های جانبی است [3]. وجود WiFi داخلی یکی از دلایل اصلی انتخاب ESP32 برای این پروژه است؛ زیرا دستگاه می تواند بدون نیاز به ماژول ارتباطی جداگانه به شبکه متصل شود.

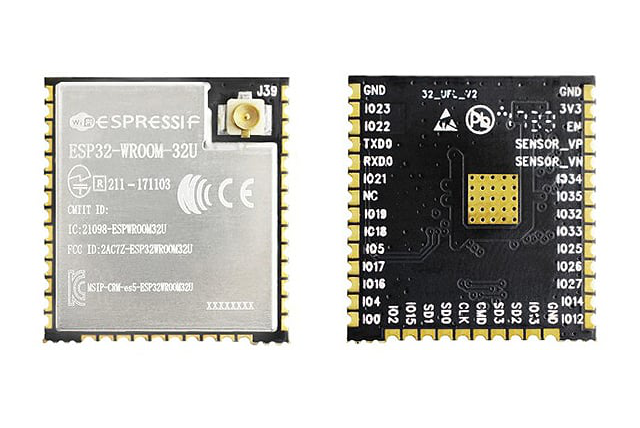
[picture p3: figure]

###### شکل (2-1) میکروکنترلر ESP32

### 2-3-1- GPIO

GPIO[^2] مخفف عبارت General Purpose Input/Output است و به پایه های ورودی و خروجی عمومی میکروکنترلر اطلاق می شود. این پایه ها قابلیت برنامه‌ریزی دارند و می توانند بسته به نیاز سیستم به عنوان ورودی یا خروجی مورد استفاده قرار گیرند. از طریق GPIO می توان وضعیت تجهیزات مختلف را دریافت یا سیگنال های کنترلی مورد نیاز را به تجهیزات خارجی ارسال کرد.

### 2-3-2- مبدل آنالوگ به دیجیتال ADC

ADC[^3] یا Analog-to-Digital Converter یکی از واحد های مهم ESP32 است که وظیفه تبدیل سیگنال های ولتاژ آنالوگ به مقادیر دیجیتال قابل پردازش توسط میکروکنترلر را بر عهده دارد. بسیاری از حسگرها خروجی خود را به صورت یک ولتاژ متغیر تولید می کنند و برای پردازش این سیگنال توسط میکروکنترلر، لازم است مقدار آن توسط ADC نمونه برداری و به یک مقدار دیجیتال تبدیل شود.

در پروژه حاضر، خروجی آنالوگ دو حسگر اصلی به ADC متصل شده است. این حسگرها شامل LDR برای اندازه گیری شدت نور محیط و MQ-2 برای تشخیص و اندازه گیری نسبی گازها و دود هستند. مقادیر خوانده شده از این حسگرها پس از تبدیل به داده دیجیتال، توسط ESP32 پردازش شده و می توانند برای پایش وضعیت محیط و اجرای منطق کنترلی سیستم مورد استفاده قرار گیرند.

ADC مورد استفاده در ESP32 دارای وضوح ۱۲ بیت است. بنابراین، در حالت ایده آل مقدار دیجیتال حاصل از تبدیل یک ورودی آنالوگ در بازه ۰ تا ۴۰۹۵ قرار می گیرد. در این حالت، مقدار صفر بیانگر کمترین مقدار قابل اندازه گیری و ۴۰۹۵ بیانگر بیشترین مقدار متناظر با محدوده اندازه گیری ADC است. مقدار واقعی خوانده شده می تواند تحت تاثیر عواملی مانند محدوده ولتاژ ورودی، کالیبراسیون ADC، نویز و شرایط مدار قرار گیرد.

## 2-4- حسگر های محیطی

حسگر های محیطی یکی از اجزای اصلی سامانه طراحی شده در این پروژه هستند و وظیفه دریافت اطلاعات مربوط به شرایط محیط اطراف را بر عهده دارند. داده های حاصل از این حسگرها توسط میکروکنترلر ESP32 دریافت و پردازش شده و در ادامه، برای پایش وضعیت محیط و اجرای عملکردهای مختلف سیستم مورد استفاده قرار می گیرند.

### 2-4-1- حسگر MQ-2

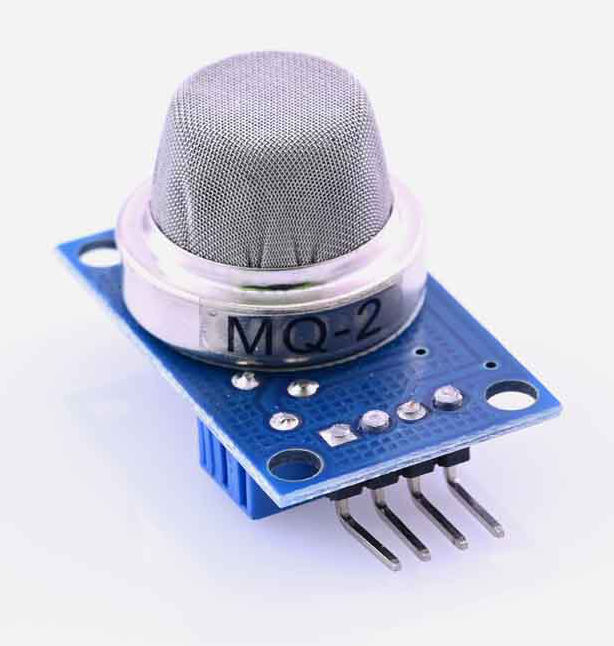
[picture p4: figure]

###### شکل (2-1) حسگر MQ-2

MQ-2 یکی از حسگر های گازی پرکاربرد از خانواده حسگر های گازی مقاومتی است که به منظور تشخیص وجود برخی گاز های قابل اشتعال و همچنین دود در محیط مورد استفاده قرار می گیرد. این حسگر به دلیل ساختار ساده و هزینه نسبتاً پایین، در پروژه های آموزشی، سامانه های پایش محیطی و برخی کاربرد های آزمایشگاهی مورد استفاده قرار می گیرد. مطابق اطلاعات فنی منتشر شده ، این حسگر برای تشخیص موادی مانند LPG، متان، پروپان، بوتان، الکل، هیدروژن و دود کاربرد دارد [7].

عملکرد MQ-2 بر اساس تغییر مقاومت الکتریکی ماده حساس به گاز در اثر قرار گرفتن در معرض گاز های موردنظر است. با تغییر غلظت گاز در محیط، مقاومت عنصر حساس تغییر کرده و در نتیجه، مشخصه الکتریکی خروجی حسگر نیز تغییر می‌کند. در ماژول های متداول MQ-2، این تغییر می تواند به صورت یک ولتاژ آنالوگ در اختیار میکروکنترلر قرار گیرد.

پیش گرمایش MQ-2

حسگر های خانواده MQ برای دستیابی به شرایط کاری نسبتاً پایدار به یک دوره گرم شدن نیاز دارند. به همین دلیل، مقدار خروجی حسگر بلافاصله پس از روشن شدن نمی تواند به عنوان یک مقدار پایدار و قابل اتکا برای تصمیم گیری در نظر گرفته شود. در این پروژه نیز پس از روشن شدن سیستم، یک دوره پیش گرمایش برای حسگر MQ-2 در نظر گرفته شده است تا عنصر حساس حسگر به شرایط کاری مناسب نزدیک شود [7].

محدودیت MQ-2

MQ-2 یک حسگر عمومی برای تشخیص وجود دود و برخی گاز های قابل اشتعال است و مقدار خروجی آن به عوامل مختلفی از جمله نوع و غلظت گاز، دمای محیط، رطوبت، مدت زمان پیش گرمایش و شرایط مدار وابسته است. بنابراین، خروجی این حسگر را نمی توان بدون کالیبراسیون و تحلیل مناسب به عنوان اندازه گیری دقیق غلظت یک گاز خاص در نظر گرفت. همچنین، MQ-2 به تنهایی یک سامانه استاندارد تشخیص و اعلام حریق محسوب نمی شود. در پروژه حاضر، این حسگر به عنوان یکی از منابع اطلاعاتی برای پایش شرایط محیط و تشخیص اولیه دود یا وجود گاز مورد استفاده قرار گرفته است و تصمیم گیری سیستم می تواند با در نظر گرفتن سایر اطلاعات محیطی انجام شود.

### 2-4-2- حسگر DHT11

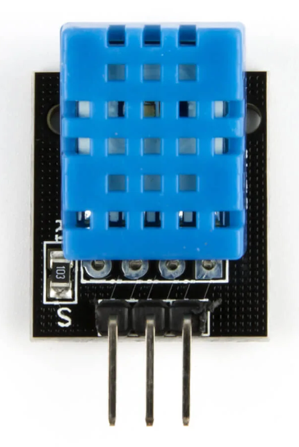
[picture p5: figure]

###### شکل (2-1) حسگر DHT11

DHT11 یک حسگر دیجیتال برای اندازه‌گیری هم زمان دما و رطوبت نسبی است. بر خلاف حسگر هایی که خروجی آنها به صورت آنالوگ ارائه می شود، DHT11 داده های اندازه گیری شده را به صورت دیجیتال و از طریق یک رابط ارتباطی مشخص به میکروکنترلر منتقل می کند. استفاده از DHT11 در این پروژه امکان پایش دو پارامتر مهم محیطی دما و رطوبت را فراهم می کند.

ارتباط DHT11 با میکروکنترلر از طریق یک خط داده و بر اساس یک پروتکل زمانبندی شده انجام می شود. در این فرایند، میکروکنترلر درخواست دریافت اطلاعات را به حسگر ارسال کرده و سپس DHT11 داده های مربوط به دما و رطوبت را از طریق خط ارتباطی به میکروکنترلر منتقل می کند. در این پروژه برای ساده سازی فرایند ارتباط و دریافت داده ها از DHT11، از کتابخانه Adafruit DHT استفاده شده است. این کتابخانه امکان ایجاد شی DHT و خواندن مستقیم دما و رطوبت را فراهم می کند. مستندات رسمی این کتابخانه توابعی مانند readTemperature() و readHumidity() را ارائه می دهد [8].

### 2-4-3- حسگر شدت نور LDR

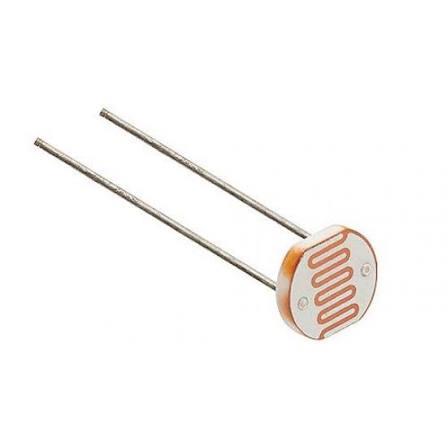
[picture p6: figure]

###### شکل (2-1) حسگر شدت نور

LDR یا Light Dependant Resistor یک مقاومت وابسته به نور است که مقدار مقاومت الکتریکی آن با میزان نور دریافتی تغییر می کند. این ویژگی باعث می شود بتوان از LDR به عنوان یک عنصر ساده برای تشخیص و پایش شدت نور محیط استفاده کرد. از آنجا که میکروکنترلر ESP32 برای دریافت این اطلاعات نیازمند یک سیگنال قابل اندازه گیری است، LDR معمولا در کنار یک مقاومت دیگر به صورت مدار تقسیم ولتاژ قرار می گیرد. در این ساختار، تغییر مقاومت LDR باعث تغییر ولتاژ خروجی مدار شده و این ولتاژ می تواند توسط ADC میکروکنترلر اندازه‌گیری شود.

### 2-4-4- حسگر تشخیص حرکت PIR

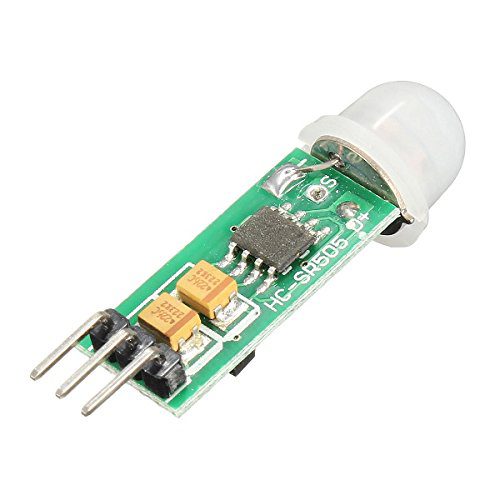
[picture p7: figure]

###### شکل (2-1) حسگر تشخیص حرکت PIR

حسگر PIR یا Passive Infrared Sensor یکی از حسگر های رایج برای تشخیص حرکت اجسام گرم، به ویژه انسان، در محیط است. این حسگر با استفاده از تغییرات تابش مادون قرمز موجود در محدوده دید خود، حرکت را تشخیص می دهد. تمام اجسام دارای دمای بالاتر از صفر مطلق، متناسب با دمای خود تابش الکترومغناطیسی منتشر می کنند که بخش قابل توجهی از آن در محدوده مادون قرمز قرار دارد. بدن انسان نیز به دلیل داشتن دمای بالاتر از محیط، تابش مادون قرمز منتشر می کند. هنگامی که یک جسم گرم در محدوده تشخیص حسگر حرکت می کند، الگوی تابش مادون قرمز دریافت شده توسط حسگر تغییر کرده و این تغییر توسط مدار PIR تشخیص داده می شود. خروجی ماژول های PIR معمولا به صورت یک سیگنال دیجیتال ارائه می شود. بنابراین، در صورت تشخیص حرکت، وضعیت خروجی تغییر کرده و میکروکنترلر می تواند این تغییر وضعیت را از طریق یکی از پایه های GPIO تشخیص دهد.

## 2-5- بازر

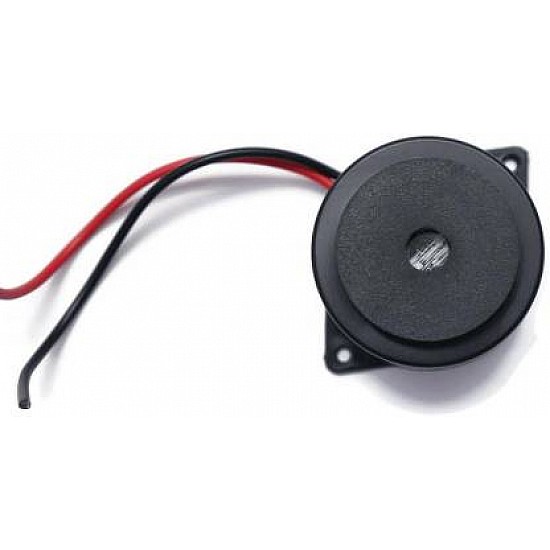
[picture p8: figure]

###### شکل (2-1) بازر

بازر یک مبدل الکتریکی به صوتی است که با دریافت یک سیگنال الکتریکی مناسب، انرژی الکتریکی را به ارتشاعات مکانیکی و در نهایت صوت تبدیل می کند. از بازر ها به دلیل ساختار ساده و قابلیت تولید صدای هشدار، در سامانه های الکترونیکی، تجهیزات اعلام وضعیت و سیستم های هشدار استفاده می شود. در پروژه حاضر، بازر به یکی از پایه های GPIO میکروکنترلر متصل شده و برای ایجاد هشدار صوتی مورد استفاده قرار گرفته است.

## 2-6- ارتباط مادون قرمز

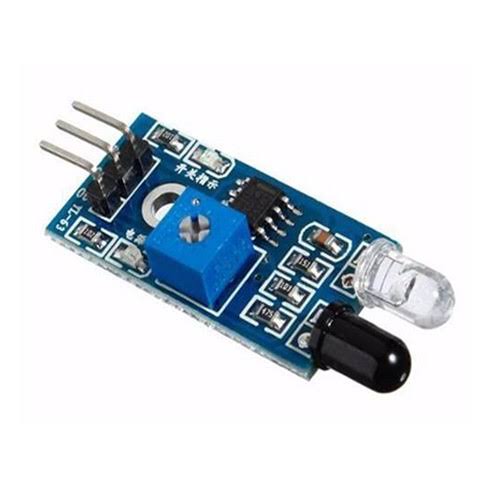
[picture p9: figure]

###### شکل (2-1) گیرنده و فرستنده مادون قرمز

مادون قرمز یا Infrared[^4] بخشی از طیف امواج الکترومغناطیسی است که طول موج آن بیشتر از نور قرمز مرئی است. این ناحیه از طیف الکترومغناطیسی در بسیاری از کاربرد های الکترونیکی و ارتباطی مورد استفاده قرار می گیرد. یکی از کاربرد های رایج مادون قرمز، استفاده در سیستم های کنترل از راه دور است که در آن اطلاعات و فرمان های دیجیتال با تغییرات زمانی شدت تابش مادون قرمز منتقل می شوند. کنترل از راه دور بسیاری از تجهیزات خانگی، از جمله تلویزیون، سیستم های تهویه مطبوع، پخش کننده های صوتی و تصویری و سایر تجهیزات الکترونیکی، بر پایه ارتباط مادون قرمز انجام می شود.

گیرنده IR وظیفه دریافت تابش مادون قرمز ارسال شده از کنترل کننده و تبدیل آن به یک سیگنال الکتریکی قابل پردازش توسط میکروکنترلر را بر عهده دارد. گیرنده با تشخیص تغییرات شدت تابش و زمان بندی پالس های دریافتی، الگوی سیگنال را در اختیار میکروکنترلر قرار می دهد. در مقابل، فرستنده IR وظیفه تبدیل سیگنال الکتریکی تولید شده توسط میکروکنترلر به تابش مادون قرمز و ارسال آن به سمت دستگاه مقصد را بر عهده دارد.

کنترل های از راه دور تجهیزات مختلف از پروتکل های ارتباطی متفاوتی برای کدگذاری و انتقال فرمان ها استفاده می کنند. هر پروتکل، ساختار و نحوه زمان بندی خاصی برای نمایش اطلاعات دارد. از جمله پروتکل های رایج مورد استفاده در تجهیزات الکترونیکی می توان به NEC، Sony، Samsung و Panasonic اشاره کرد. تفاوت میان این پروتکل ها در نحوه کدگذاری داده ها، ساختار فریم، زمان بندی پالس ها و سایر مشخصات سیگنال است.

در این پروژه برای پیاده سازی قابلیت دریافت و ارسال سیگنال های مادون قرمز از کتابخانه IRremoteESP8266 استفاده شده است. این کتابخانه یک پروژه متن باز برای پلتفرم های ESP8266 و ESP32 است که امکانات لازم برای دریافت، پردازش و ارسال سیگنال های مادون قرمز را فراهم می کند. کتابخانه IRremoteESP8266 از طیف گسترده ای از پروتکل های رایج کنترل از راه دور و انواع مختلف گیرنده ها و فرستنده های مادون قرمز پشتیبانی می کند [6]. به این ترتیب، بخش مادون قرمز سیستم علاوه بر امکان دریافت فرمان های کنترل از راه دور، قابلیت ذخیره و بازپخش فرمان های IR را نیز فراهم می کند. این قابلیت یکی از بخش های اصلی عملکرد کنترلی دستگاه بوده و امکان استفاده از ESP32 به عنوان واسطی برای کنترل تجهیزات الکترونیکی مجهز به گیرنده مادون قرمز را فراهم می سازد.

## 2-7- ارتباط رادیویی RF

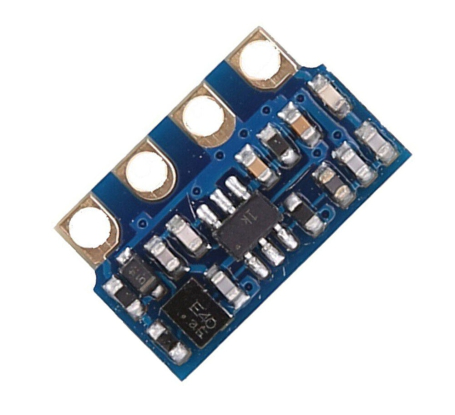
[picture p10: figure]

###### شکل (2-1) گیرنده رادیویی

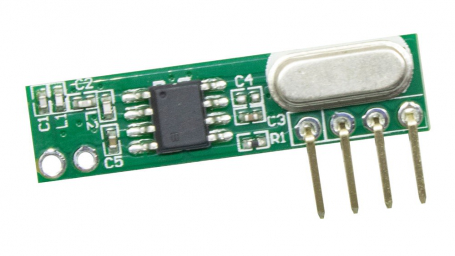
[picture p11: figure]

###### شکل (2-2) فرستنده رادیویی

فرکانس رادیویی[^5] یا Radio Frequency به بخشی از طیف امواج الکترومغناطیسی گفته می شود که می توان از آن برای انتقال اطلاعات به صورت بی‌سیم استفاده کرد. ارتباطات RF در بسیاری از سامانه های الکترونیکی و تجهیزات کنترل از راه دور مورد استفاده قرار می گیرند و امکان انتقال داده بدون نیاز به اتصال فیزیکی میان فرستنده و گیرنده را فراهم می کند. یک سیستم رادیویی ساده می تواند از دو بخش اصلی، یعنی فرستنده و گیرنده تشکیل شود. فرستنده وظیفه تبدیل اطلاعات یا کد کنترلی به یک سیگنال رادیویی و ارسال آن را بر عهده دارد. در طرف مقابل، گیرنده سیگنال های رادیویی را دریافت کرده و آن را به یک سیگنال الکتریکی قابل پردازش تبدیل می کند. در تجهیزات کنترل از راه دور رایج، باند های فرکانسی ۳۱۵ و ۴۳۳ مگاهرتز از جمله فرکانس های مورد استفاده هستند.

کتابخانه RCSwitch یکی از کتابخانه های پر کاربرد برای کار با برخی تجهیزات RF ساده در باند های فرکانسی ۳۱۵ و ۴۳۳ مگاهرتز است. این کتابخانه امکانات لازم برای دریافت و ارسال کد های رادیویی مورد استفاده در بسیاری از کنترل های از راه دور ساده را فراهم می کند [5]. با استفاده از RCSwitch، می توان سیگنال های دریافتی از گیرنده RF را توسط میکروکنترلر دریافت و کد مربوط به آن را استخراج کرد. سپس در صورت نیاز، همان کد می تواند از طریق ماژول فرستنده RF مجددا ارسال شود. این قابلیت امکان پیاده سازی عملکرد دریافت، ذخیره و بازپخش کد های RF را در سیستم فراهم می کند.

## 2-8- ارتباط WiFi

WiFi یک فناوری ارتباطی بی‌سیم مبتنی بر مجموعه استاندارد های IEEE 802.11 است که امکان برقراری ارتباط و تبادل داده میان تجهیزات مختلف را از طریق شبکه بی‌سیم فراهم می کند. این فناوری به دلیل سهولت استفاده، پوشش مناسب و پشتیبانی گسترده در تجهیزات الکترونیکی، یکی از روش های متداول برای اتصال تجهیزات هوشمند و سامانه های اینترنت اشیا به شبکه محسوب می شود. میکروکنترلر ESP32 به صورت داخلی از قابلیت WiFi پشتیبانی می کند و امکان برقراری ارتباط با شبکه های بی‌سیم مبتنی بر استاندارد های 802.11b/g/n را فراهم می سازد [3]. وجود این قابلیت داخلی باعث می شود ESP32 بدون نیاز به استفاده از یک ماژول ارتباطی خارجی بتواند به شبکه متصل شده و داده های موردنیاز را ارسال یا دریافت کند.

ESP32 می تواند در چند حالت مختلف برای برقراری ارتباط WiFi مورد استفاده قرار گیرد. یکی از حالت های اصلی، Station یا STA است. در این حالت، ESP32 همانند یک Client به یک Access Point موجود، مانند روتر یا مودم، متصل می شود. پس از برقراری اتصال، ESP32 می تواند از طریق شبکه به سایر تجهیزات و سرویس های موجود دسترسی داشته باشد [9]. حالت دیگر، Access Point یا AP است. در این حالت، خود ESP32 نقش نقطه دسترسی بی‌سیم را بر عهده گرفته و یک شبکه WiFi ایجاد می کند. سایر تجهیزات می‌توانند مستقیماً به شبکه ایجاد شده توسط ESP32 متصل شوند. این حالت به ویژه در شرایطی که دستگاه هنوز به شبکه اصلی دسترسی ندارد یا نیاز به انجام تنظیمات اولیه وجود دارد، کاربرد دارد [9]. همچنین ESP32 از حالت AP+STA پشتیبانی می کند. در این حالت، ESP32 به صورت همزمان از طریق رابط STA به شبکه اصلی متصل شده و در نقش Access Point نیز یک شبکه WiFi ایجاد می کند. بنابراین، سایر تجهیزات می توانند به شبکه ایجاد شده توسط ESP32 متصل شوند، در حالی که خود ESP32 همچنان ارتباط خود را با شبکه اصلی حفظ کرده است [9]. این قابلیت در فرایند پیکربندی اولیه دستگاه می تواند کاربرد ویژه‌ای داشته باشد.

### 2-8-1- Captive Portal

Captive Portal[^6] روشی برای ارائه یک صفحه وب یا رابط تنظیمات به کاربر پس از اتصال به یک شبکه است. در این روش، دستگاه کاربر پس از اتصال به شبکه بی‌سیم، به جای دسترسی مستقیم به مقصد موردنظر، به صفحه ای هدایت می شود که می تواند برای انجام تنظیمات یا ورود اطلاعات مورد استفاده قرار گیرد. در پروژه حاضر، از Captive Portal به منظور پیکربندی اولیه دستگاه استفاده شده است. هنگامی که ESP32 برای نخستین بار راه اندازی می‌شود یا اطلاعات شبکه مورد نیاز را در اختیار ندارد، می تواند در حالت Access Point یک شبکه بی‌سیم ایجاد کند. کاربر با اتصال تلفن همراه یا رایانه به این شبکه، به صفحه تنظیمات دستگاه دسترسی پیدا کرده و اطلاعات مورد نیاز، مانند مشخصات شبکه WiFi و سایر تنظیمات ارتباطی، را وارد می‌کند.

## 2-9- پروتکل MQTT

MQTT[^7] یا Message Queuing Telemetry Transport یک پروتکل پیام رسانی سبک و کم حجم است که بر اساس معماری Client/Server و الگوی ارتباطی Publish/Subscribe طراحی شده است. این پروتکل به طور ویژه برای سامانه های اینترنت اشیا، تجهیزات دارای منابع پردازشی و حافظه محدود و شبکه هایی با پهنای باند محدود مورد استفاده قرار می گیرد. استاندارد MQTT نسخه 5.0 توسط سازمان OASIS منتشر شده است [4]. یکی از مهم ترین ویژگی های MQTT، سربار کم و سادگی ساختار پیام ها است. این ویژگی باعث می شود این پروتکل برای ارتباط میان میکروکنترلر ها، حسگرها و سایر تجهیزات هوشمند مناسب باشد. همچنین MQTT با استفاده از معماری Publish/Subscribe، فرستنده و گیرنده پیام را از یکدیگر جدا می کند و مدیریت ارتباط میان آنها را به یک مولفه مرکزی به نام Broker واگذار می کند.

### 2-9-1- MQTT Broker[^8]

Broker هسته مرکزی ارتباط در معماری MQTT است و وظیفه دریافت، مدیریت و ارسال پیام ها را بر عهده دارد. هنگامی که یک Client پیامی را در یک Topic منتشر می کند، Broker پیام را دریافت کرده و آن را برای Client هایی که آن Topic را Subscribe کرده اند ارسال می کند. Client ای که یک پیام را در یک Topic منتشر می کند، Publisher نامیده می شود. در مقابل، Client ای که برای دریافت پیام های مربوط به یک Topic ثبت‌نام می کند، Subscriber نام دارد. بنابراین، یک Client می تواند همزمان نقش Publisher و Subscriber را داشته باشد. Topic یک مسیر منطقی برای دسته بندی و شناسایی پیام های MQTT است. هر پیام در یک Topic مشخص منتشر می شود و Subscriber ها با Subscribe کردن به Topic موردنظر، پیام های مربوط به آن را دریافت می کنند. Topic ها معمولاً به صورت سلسله مراتبی تعریف می شوند تا دسته بندی و مدیریت پیام ها ساده تر شود.

ساختار کلی Topic ها به صورت زیر است:

<topic> / <subtopic> / <subtopic>

Payload[^9] بخش اصلی محتوای پیام MQTT است که داده موردنظر را در خود نگهداری می‌کند. استاندارد MQTT قالب مشخصی برای محتوای Payload تعیین نمی کند و انتخاب قالب داده به طراح سیستم واگذار شده است. بنابراین، Payload می تواند به صورت متن ساده، JSON یا سایر قالب های مناسب برای کاربرد موردنظر ارسال شود [4].

### 2-9-2- کیفیت سرویس

یکی از قابلیت های مهم MQTT، پشتیبانی از سطوح مختلف Quality of Service (QoS) است. QoS مشخص می کند که پیام ها با چه سطحی از تضمین تحویل میان Client و Broker منتقل شوند. MQTT سه سطح QoS را تعریف می کند [4]:

QoS 0- حداکثر یک بار (At Most One):

در این سطح، پیام فقط یکبار ارسال می شود و هیچ تضمینی برای تحویل موفق پیام وجود ندارد. در نتیجه، در صورت بروز خطا یا قطع ارتباط، ممکن است پیام به مقصد نرسد. این سطح کمترین سربار ارتباطی را دارد و برای داده هایی که از دست رفتن برخی نمونه های آنها اهمیت زیادی ندارد، مناسب است.

QoS 1- حداقل یک بار (At Least Once):

در این سطح، تحویل پیام به مقصد تضمین می شود، اما در برخی شرایط ممکن است یک پیام بیش از یک بار دریافت شود. بنابراین، گیرنده باید در صورت نیاز امکان مدیریت پیام های تکراری را داشته باشد.

QoS 2- دقیقا یک بار (Exactly Once):

در این سطح، پروتکل سازوکاری برای اطمینان از تحویل پیام به صورت دقیقا یک بار در نظر می گیرد. این سطح بیشترین میزان اطمینان و در نتیجه سربار و پیچیدگی بیشتری نسبت به دو سطح دیگر دارد.

### 2-9-3- ارتباط MQTT از طریق WebSocket

مرورگر های وب به صورت معمول برای برقراری ارتباط مستقیم با MQTT Broker از طریق اتصال TCP خام طراحی نشده اند. به همین دلیل، برای ایجاد ارتباط میان یک برنامه تحت وب و MQTT Broker معمولاً از WebSocket[^10] استفاده می‌شود. WebSocket یک ارتباط دو طرفه و پایدار میان Browser و Server ایجاد می‌کند و امکان ارسال و دریافت داده را بدون نیاز به ایجاد یک اتصال جدید برای هر پیام فراهم می سازد.

در این روش، مرورگر از طریق WebSocket به سرویسی متصل می شود که امکان ارتباط MQTT روی WebSocket را فراهم کرده است. پس از برقراری اتصال، برنامه تحت وب می تواند همانند یک Client MQTT در Topicهای موردنظر Subscribe کرده یا پیام هایی را در Topicهای مشخص منتشر کند.

## 2-10- ذخیره سازی اطلاعات در ESP32

ESP32 دارای حافظه Flash برای نگهداری Firmware و داده های دائمی است. از این حافظه می توان برای اطلاعاتی استفاده کرد که باید بعد از restart نیز باقی بماند. LittleFS[^11] یک فایل سیستم مناسب برای حافظه Flash سیستم های نهفته است. در Arduino-ESP32، LittleFS به عنوان یکی از فایل سیستم های قابل استفاده در ESP32 معرفی شده است [10]

# فصل 3: تحلیل و طراحی سیستم

در این فصل، فرایند تحلیل و طراحی سامانه هوشمند پایش محیط و کنترل تجهیرات مبتنی بر اینترنت اشیا ارائه می شود. هدف از طراحی این سامانه، ایجاد یک هاب هوشمند مبتنی بر میکروکنترلر ESP32 است که بتواند ضمن دریافت و پردازش اطلاعات محیطی، امکان ارسال داده ها از طریق شبکه بی‌سیم، ایجاد هشدار در شرایط مشخص و همچنین دریافت و بازپخش سیگنال های کنترلی مادون قرمز و فرکانس رادیویی را فراهم کند.

سامانه طراحی شده از مجموعه ای از حسگر های محیطی شامل حسگر دما و رطوبت DHT11، حسگر دود و گاز MQ-2، حسگر نور مبتنی بر LDR و حسگر تشخیص حرکت PIR تشکیل شده است. داده های حاصل از این حسگر ها توسط ESP32 دریافت و پردازش شده و در بازه های زمانی مشخص از طریق شبکه WiFi به MQTT Broker ارسال می شوند.

علاوه بر قابلیت پایش محیط، سامانه دارای زیرسیستم ارتباطی RF در دو باند فرکانسی ۳۱۵ و ۴۳۳ مگاهرتز و یک زیرسیستم ارتباط مادون قرمز است. این زیرسیستم ها امکان دریافت، ذخیره سازی و بازپخش برخی سیگنال های کنترلی تجهیزات مختلف را فراهم می کنند. به این ترتیب، ESP32 به عنوان یک واسط میان تجهیزات فیزیکی، شبکه و رابط کاربری عمل می کند.

## 3-1- تحلیل نیازمندی های سیستم

با توجه به اهداف پروژه و قابلیت های مورد انتظار از سامانه، نیازمندی های سیستم به دو گروه اصلی نیازمندی های عملکردی و نیازمندی های غیرعملکردی تقسیم می شوند. نیازمندی های عملکردی بیان کننده وظایف و قابلیت هایی هستند که سامانه باید ارائه دهد و نیازمندی های غیرعملکردی نیز ویژگی های کیفی و الزامات مربوط به نحوه عملکرد، توسعه، نگهداری و پایداری سیستم را مشخص می کنند. در طراحی سامانه حاضر، هدف اصلی ایجاد یک دستگاه هوشمند برای پایش شرایط محیطی، تشخیص وضعیت های غیرعادی، ایجاد هشدار و فراهم کردن امکان کنترل تجهیزات الکترونیکی از طریق شبکه است؛ بنابراین، مجموعه نیازمندی های تعریف شده باید علاوه بر پوشش عملکرد های اصلی دستگاه، امکان ارتباط میان بخش سخت افزاری، نرم‌افزار Firmware، سرور یا MQTT Broker و رابط کاربری تحت وب را نیز فراهم کند.

از نظر نیازمندی های عملکردی، سامانه باید قادر باشد اطلاعات محیطی مختلف را توسط حسگرهای متصل به ESP32 دریافت و پردازش کند؛ به این صورت که دمای محیط و رطوبت نسبی توسط حسگر DHT11، شدت نور توسط LDR، تغییرات ناشی از وجود دود یا برخی گازها توسط MQ-2 و حرکت در محیط توسط حسگر PIR شناسایی و اندازه گیری شوند. اطلاعات دریافت شده از حسگرها باید توسط میکروکنترلر پردازش شده و در صورت عبور پارامتر های مشخص، به‌ویژه مقدار مربوط به دود یا گاز، از آستانه تعیین شده، سیستم بتواند وضعیت هشدار را فعال کرده و با استفاده از بازر هشدار صوتی ایجاد کند. همچنین سامانه باید امکان انتقال اطلاعات حسگرها و وضعیت فعلی دستگاه را از طریق شبکه WiFi فراهم کرده و بتواند با یک MQTT Broker ارتباط برقرار کند؛ به گونه ای که داده های مربوط به حسگرها و وضعیت سیستم در Topic های مشخص منتشر شده و فرمان های دریافتی از طریق MQTT نیز توسط ESP32 دریافت، پردازش و اجرا شوند.

یکی دیگر از نیازمندی های اصلی سامانه، فراهم کردن امکان کنترل تجهیزات الکترونیکی از طریق سیگنال های RF و IR است. در این راستا، سیستم باید قابلیت دریافت سیگنال های RF در دو باند فرکانسی ۳۱۵ و ۴۳۳ مگاهرتز و همچنین دریافت سیگنال های مادون قرمز را داشته باشد و بتواند سیگنال های دریافت شده را در حافظه ذخیره کند تا در زمان موردنظر مجددا از طریق فرستنده مربوطه ارسال شوند. بنابراین، سامانه باید علاوه بر دریافت سیگنال، قابلیت ذخیره‌سازی و بازپخش سیگنال های RF و IR را نیز داشته باشد و اطلاعات ذخیره شده باید پس از خاموش و روشن شدن دستگاه همچنان قابل دسترسی باشند. همچنین برای جلوگیری از وابستگی تنظیمات دستگاه به کد Firmware،سامانه باید امکان تنظیم اطلاعات شبکه WiFi و مشخصات MQTT را بدون نیاز به تغییر و کامپایل مجدد برنامه فراهم کند؛ به همین منظور، فرآیند پیکربندی اولیه از طریق یک پورتال تنظیمات انجام شده و کاربر می تواند اطلاعات موردنیاز را از طریق رابط ارائه شده وارد یا تغییر دهد.

در کنار عملکردهای محلی، سامانه باید یک رابط کاربری تحت وب نیز در اختیار کاربر قرار دهد تا اطلاعات دریافت شده از حسگرها و وضعیت کلی سیستم در آن نمایش داده شود و کاربر بتواند فرمان های کنترلی موردنظر خود را ارسال کند. ارتباط میان داشبورد تحت وب و بخش ارتباطی سیستم بر پایه MQTT انجام شده و برای فراهم کردن امکان ارتباط MQTT در محیط مرورگر از WebSocket استفاده می‌شود؛ در نتیجه، اطلاعات حسگرها می‌توانند در داشبورد نمایش داده شده و فرمان های کاربر نیز از طریق همین مسیر به دستگاه منتقل شوند. این ساختار باعث می‌شود کاربر بتواند بدون نیاز به دسترسی مستقیم به سخت افزار، وضعیت محیط را مشاهده کرده و تجهیزات متصل به سامانه را کنترل کند.

از نظر نیازمندی های غیرعملکردی، ساختار سیستم باید به گونه ای طراحی شود که امکان توسعه و نگهداری آن در آینده وجود داشته باشد. به همین منظور، Firmware سامانه به صورت ماژولار طراحی شده و بخش هایی مانند مدیریت حسگرها، ارتباط MQTT، ارتباط RF، ارتباط IR، مدیریت هشدار و مدیریت حافظه از یکدیگر تفکیک شده اند تا اضافه کردن قابلیت های جدید یا اصلاح یک بخش، حداقل تأثیر را بر سایر قسمت های سیستم داشته باشد. همچنین اطلاعات مربوط به شبکه و سیگنال های ذخیره شده نباید با خاموش شدن دستگاه از بین بروند؛ بنابراین از سیستم فایل LittleFS برای ذخیره‌سازی پایدار این اطلاعات استفاده شده است. یکی دیگر از الزامات مهم، پایداری عملکرد محلی سیستم است؛ به این معنا که قطع ارتباط با MQTT Broker یا بروز اختلال در شبکه نباید باعث توقف عملکرد هایی مانند خواندن حسگرها، تشخیص حرکت یا فعال سازی سیستم هشدار شود و بخش های اصلی دستگاه باید بتوانند مستقل از وضعیت ارتباط شبکه به عملکرد خود ادامه دهند.

در نهایت، مجموعه این نیازمندی ها مشخص می‌کند که سامانه طراحی شده تنها یک دستگاه اندازه‌گیری ساده نیست، بلکه یک سیستم هوشمند یکپارچه است که وظایف پایش محیط، تشخیص شرایط غیرعادی، ایجاد هشدار، ارتباط شبکه ای، دریافت و بازپخش سیگنال هایRF و IR، ذخیره‌سازی اطلاعات و کنترل تجهیزات از طریق رابط کاربری تحت وب را بر عهده دارد. بنابراین، نیازمندی های تعیین شده به عنوان مبنایی برای طراحی معماری سخت افزار و نرم افزار سیستم مورد استفاده قرار گرفته اند و در مراحل بعدی طراحی و پیاده سازی، عملکرد اجزای مختلف سامانه بر اساس این نیازمندی ها تعیین و ارزیابی خواهد شد.

## 3-2- معماری کلی سیستم

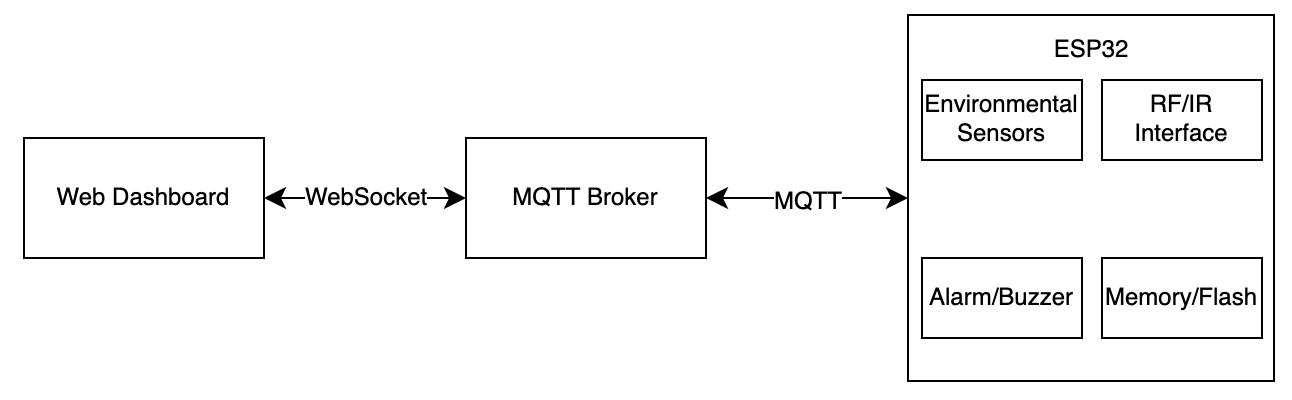
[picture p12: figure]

###### شکل (3-1) معماری کلی سیستم

معماری سامانه به گونه ای طراحی شده است که میکروکنترلر ESP32 به عنوان هسته اصلی پردازشی و ارتباطی، در مرکز تعامل میان حسگرها، تجهیزات کنترلی، زیرساخت شبکه و کاربر قرار گیرد. در این معماری، اطلاعات مربوط به شرایط محیطی توسط حسگرهای متصل به ESP32 دریافت شده و پس از پردازش، از طریق شبکه WiFi و پروتکل MQTT به زیرساخت ارتباطی سامانه ارسال می‌شوند. ESP32 علاوه بر دریافت و پردازش اطلاعات حسگرها، مسئولیت مدیریت سیستم هشدار، دریافت و ارسال سیگنال های RF وIR ، ذخیره‌سازی اطلاعات و اجرای فرمان های کنترلی را نیز بر عهده دارد.

در سمت کاربر، یک داشبورد تحت وب برای نمایش اطلاعات و کنترل سامانه در نظر گرفته شده است. کاربر می تواند از طریق این داشبورد وضعیت فعلی حسگرها و سایر بخش های سیستم را مشاهده کرده و فرمان های کنترلی موردنظر خود را ارسال کند. فرمان های ارسال شده توسط کاربر ابتدا از طریق ارتباط WebSocket به MQTT Broker منتقل شده و سپس در قالب پیام MQTT در اختیار ESP32 قرار می گیرند. ESP32 پس از دریافت پیام، فرمان مربوطه را پردازش کرده و عملیات موردنظر را اجرا می‌کند. به این ترتیب، ارتباط میان سخت افزار و کاربر به صورت دوطرفه برقرار بوده و هم اطلاعات دستگاه به سمت کاربر ارسال می شوند و هم فرمان های کاربر به دستگاه منتقل می شوند.

به صورت کلی، معماری سامانه را می توان از نظر عملکردی به سه بخش اصلی شامل لایه سخت افزار و جمع آوری داده، لایه پردازش و کنترل مبتنی بر ESP32 و لایه ارتباطی و رابط کاربر تقسیم کرد. این تفکیک به منظور مشخص کردن وظایف هر بخش و کاهش وابستگی میان اجزای مختلف سیستم انجام شده است. نقشه شماتیک کامل مدار و نحوه اتصال اجزای سخت افزاری در پیوست ‏8-1- ارائه شده است.

### 3-2-1- لایه سخت افزار و جمع آوری داده

در لایه سخت افزار و جمع آوری داده، مجموعه ای از حسگرها و ماژول های ارتباطی به ESP32 متصل شده اند که وظیفه آنها دریافت اطلاعات از محیط و برقراری ارتباط با تجهیزات خارجی است. حسگر DHT11 برای اندازه گیری دما و رطوبت نسبی، حسگر MQ-2 برای تشخیص تغییرات ناشی از وجود دود و برخی گازها، حسگر LDR برای پایش شدت نور محیط و حسگر PIR برای تشخیص حرکت مورد استفاده قرار گرفته اند. خروجی این حسگرها بسته به نوع آنها به صورت دیجیتال یا آنالوگ در اختیار ESP32 قرار گرفته و توسط نرم‌افزار Firmware پردازش می‌شوند.

علاوه بر حسگرهای محیطی، در این لایه تجهیزات ارتباطی مربوط به کنترل تجهیزات خارجی نیز قرار دارند. سامانه دارای گیرنده و فرستنده RF برای باندهای فرکانسی ۳۱۵ و ۴۳۳ مگاهرتز و همچنین گیرنده و فرستنده مادون قرمز IR است. این تجهیزات امکان دریافت سیگنال های کنترلی، ذخیره‌سازی اطلاعات مربوط به آنها و ارسال مجدد سیگنال های ذخیره شده را فراهم می کنند. در نتیجه، لایه سخت افزاری علاوه بر جمع آوری اطلاعات محیطی، وظیفه ایجاد واسط میان ESP32 و تجهیزات خارجی قابل کنترل را نیز بر عهده دارد.

### 3-2-2- لایه پردازش و کنترل

ESP32 هسته اصلی پردازش و کنترل سامانه است و وظیفه مدیریت بخش عمده ای از عملیات سیستم را بر عهده دارد. داده های دریافت شده از حسگرها در این لایه پردازش شده و وضعیت فعلی محیط تعیین می شود. همچنین منطق مربوط به سیستم هشدار در این بخش اجرا شده و در صورت برقرار شدن شرایط تعریف شده، بازر فعال می‌شود. مدیریت گیرنده ها و فرستنده های RF و IR، پردازش فرمان های دریافتی از MQTT، مدیریت اطلاعات ذخیره شده و برقراری ارتباط با MQTT Broker نیز در این لایه انجام می‌شود.

Firmware مربوط به ESP32 به صورت ماژولار طراحی شده است تا وظایف مختلف سیستم از یکدیگر تفکیک شوند. برای هر یک از حسگرهای اصلی، از جمله DHT11، MQ-2، LDR و PIR، بخش های نرم افزاری مربوطه در نظر گرفته شده و مدیریت ارتباط RF، ارتباط IR، MQTT، حافظه، هشدار و LED نیز در ماژول های مستقل انجام می شود. این ساختار باعث می شود هر بخش مسئولیت مشخصی داشته باشد و تغییر، اصلاح یا توسعه یک قابلیت، وابستگی کمتری به سایر بخش های نرم افزار ایجاد کند. همچنین این معماری امکان اضافه کردن قابلیت ها و تجهیزات جدید را در مراحل بعدی توسعه ساده تر می کند.

### 3-2-3- لایه ارتباطی و رابط کاربر

ارتباط میان ESP32 و زیرساخت نرم افزاری سامانه از طریق WiFi برقرار می شود. پس از اتصال ESP32 به شبکه، اطلاعات اندازه گیری شده و وضعیت سیستم در قالب پیام های MQTT به MQTT Broker ارسال می شوند. در این پروژه از broker.emqx.io به عنوان Broker مورد استفاده در ارتباطات MQTT استفاده شده است. ESP32 می تواند اطلاعات حسگرها و وضعیت بخش های مختلف سیستم را در Topic های مشخص منتشر کرده و همچنین پیام ها و فرمان های کنترلی دریافت شده از طریق MQTT را پردازش کند.

داشبورد تحت وب نیز به منظور فراهم کردن امکان پایش و کنترل سیستم برای کاربر طراحی شده است. این داشبورد از طریق WebSocket به MQTT Broker متصل می‌شود و می تواند پیام های منتشر شده توسط ESP32 را دریافت کرده و اطلاعاتی مانند وضعیت حسگرها، مقادیر اندازه گیری شده و وضعیت هشدار را به کاربر نمایش دهد. از طرف دیگر، فرمان هایی که کاربر از طریق داشبورد ارسال می‌کند، در قالب پیام MQTT به سمت ESP32 منتقل شده و پس از دریافت توسط دستگاه، توسط بخش مدیریت فرمان پردازش و اجرا می‌شوند.

## 3-3- طراحی سخت افزار

در طراحی سخت افزاری سامانه، ماژول ESP32-WROOM-32 به عنوان واحد پردازشی و کنترلی اصلی انتخاب شده است. انتخاب این ماژول با توجه به قابلیت پردازشی مناسب، تعداد کافی پایه های ورودی و خروجی، برخورداری از مبدل آنالوگ به دیجیتال(ADC)، حافظه مناسب و همچنین پشتیبانی داخلی از ارتباط WiFi انجام شده است. ESP32 در این سامانه نقش هسته مرکزی را بر عهده دارد و تمامی اجزای سخت افزاری شامل حسگر های محیطی، تجهیزات دریافت و ارسال RF و IR، سیستم هشدار و رابط های ارتباطی به صورت مستقیم یا غیرمستقیم با آن در ارتباط هستند. این ساختار باعث شده است که پردازش اطلاعات، کنترل تجهیزات، ذخیره سازی داده ها و ارتباط با زیرساخت نرم افزاری سیستم در یک واحد مرکزی انجام شود.

### 3-3-1- واحد پردازش مرکزی و اتصال حسگرها

ماژول ESP32-WROOM-32 وظیفه دریافت اطلاعات حسگرها، پردازش داده های دریافتی، اجرای منطق کنترلی و هشدار، مدیریت تجهیزات RF و IR، ذخیره سازی اطلاعات و برقراری ارتباط با شبکه را بر عهده دارد. قابلیت WiFi داخلی ESP32 برای اتصال سامانه به شبکه محلی و برقراری ارتباط با MQTT Broker مورد استفاده قرار گرفته است و پایه های GPIO نیز برای اتصال تجهیزات دیجیتال و کنترل برخی ماژول ها به کار گرفته شده اند. همچنین برای دریافت خروجی آنالوگ حسگر هایی مانند MQ-2 و LDR از پایه های دارای قابلیت ADC استفاده شده است.

برای اندازه‌گیری دمای محیط و رطوبت نسبی از حسگر DHT11 استفاده شده است. این حسگر از طریق یک خط داده دیجیتال با ESP32 ارتباط برقرار می کند و اطلاعات اندازه گیری شده را به صورت دیجیتال در اختیار میکروکنترلر قرار می دهد. در پیاده‌سازی Firmware، برای ارتباط با DHT11 از کتابخانه Adafruit DHT و توابع readTemperature() و readHumidity() استفاده شده است و پایه داده حسگر به GPIO15 متصل شده است. اطلاعات دریافت شده پس از پردازش در Firmware، به صورت جداگانه برای دما و رطوبت مدیریت شده و از طریق MQTT در اختیار سایر بخش های سامانه و داشبورد تحت وب قرار می گیرند.

برای پایش وجود دود و برخی گاز های قابل اشتعال از حسگر MQ-2 استفاده شده است. در این پروژه خروجی آنالوگ این حسگر به GPIO33 متصل شده و مقدار آن توسط ADC داخلی ESP32 اندازه گیری می شود. حسگر MQ-2 برای دستیابی به شرایط کاری مناسب به یک دوره پیش گرمایش نیاز دارد و بنابراین مقدار خروجی آن بلافاصله پس از راه اندازی سیستم به عنوان یک مقدار پایدار در نظر گرفته نمی شود. در طراحی حاضر، فرایند راه‌اندازی و گرم شدن حسگر مطابق ساختار مدار و Firmware سیستم مدیریت می شود و پس از آماده شدن حسگر، مقدار خروجی آن توسط ADC خوانده می شود. مقدار به دست آمده علاوه بر ارسال از طریق MQTT، با یک آستانه از پیش تعیین شده مقایسه می شود و در صورت عبور مقدار اندازه گیری شده از آستانه، وضعیت هشدار فعال شده و بازر به صدا در می آید؛ همچنین وضعیت هشدار از طریق MQTT به داشبورد ارسال می‌شود تا کاربر بتواند وضعیت سیستم را مشاهده کند.

برای پایش شدت نور محیط نیز از LDR استفاده شده است. از آنجا که خروجی LDR به صورت تغییرات ولتاژ در یک مدار اندازه گیری ایجاد می شود، خروجی آن به یکی از ورودی های ADC متصل شده است. در این پروژه خروجی مربوط به LDR به GPIO32 متصل شده و مقدار آن توسط ADC داخلی ESP32 خوانده می شود. Firmware در بازه های زمانی مشخص مقدار خروجی را نمونه برداری کرده و مقدار حاصل را برای پایش وضعیت روشنایی محیط از طریق MQTT منتشر می کند.

به منظور تشخیص حرکت در محیط از یک ماژول PIR استفاده شده است که خروجی دیجیتال آن به GPIO13 متصل شده است. هنگامی که حسگر وجود حرکت را در محدوده تحت پوشش خود تشخیص دهد، وضعیت خروجی دیجیتال آن تغییر کرده و ESP32 این تغییر وضعیت را دریافت و پردازش می کند. وضعیت تشخیص حرکت پس از پردازش توسط Firmware از طریق MQTT منتشر می شود و در صورت فعال بودن قابلیت هشدار حرکت، وقوع حرکت می تواند موجب فعال شدن سیستم هشدار صوتی و ارسال وضعیت مربوطه به داشبورد شود.

### 3-3-2- سیستم ارتباط فرکانس رادیویی

یکی از قابلیت های اصلی سامانه، امکان دریافت، ذخیره سازی و بازپخش سیگنال های فرکانس رادیویی در دو باند ۳۱۵ و ۴۳۳ مگاهرتز است. با توجه به تفاوت فرکانسی این دو گروه، برای هر باند یک گیرنده و یک فرستنده مستقل در نظر گرفته شده است تا ESP32 بتواند دریافت و ارسال سیگنال ها را به صورت جداگانه مدیریت کند. در بخش مربوط به باند ۳۱۵ مگاهرتز، از ماژول گیرنده RXB61 و ماژول فرستنده H34S استفاده شده است که خروجی داده گیرنده به GPIO22 و ورودی داده فرستنده به GPIO23 متصل شده اند. برای باند ۴۳۳ مگاهرتز نیز از گیرنده RXB35 و فرستنده H34S استفاده شده است که خروجی گیرنده به GPIO14 و ورودی داده فرستنده به GPIO27 متصل شده اند.

در فرایند دریافت سیگنال، ESP32 اطلاعات دریافتی از گیرنده های RF را دریافت و توسط Firmware پردازش می‌کند. سیگنال های موردنظر پس از دریافت می توانند با یک نام مشخص در حافظه سیستم ذخیره شوند تا در زمان دیگری امکان استفاده مجدد از آنها وجود داشته باشد. در هنگام ارسال نیز، Firmware بر اساس اطلاعات ذخیره شده و باند فرکانسی مربوط به سیگنال، فرستنده مناسب را انتخاب کرده و داده موردنظر را برای بازپخش به آن ارسال می کند. برای پیاده سازی بخش دریافت و ارسال سیگنال های RF از کتابخانه RCSwitch استفاده شده است که امکان کار با بسیاری از تجهیزات کنترل از راه دور RF ساده در باندهای موردنظر را فراهم می‌کند.

### 3-3-3- سیستم ارتباط مادون قرمز

برای فراهم کردن قابلیت دریافت و بازپخش سیگنال های مادون قرمز، از یک گیرنده IR و مجموعه‌ای شامل چهار LED مادون قرمز استفاده شده است. گیرنده مادون قرمز به GPIO17 متصل شده و LED های فرستنده مادون قرمز از طریق GPIO4 کنترل می شوند. گیرنده IR سیگنال های ارسال شده توسط کنترل های مادون قرمز را دریافت کرده و اطلاعات مربوط به سیگنال توسط ESP32 پردازش می‌شود. سیگنال های دریافت شده می توانند با یک نام مشخص در حافظه سیستم ذخیره شوند تا در زمان دیگری قابل بازیابی و بازپخش باشند. در فرایند ارسال، ESP32 اطلاعات سیگنال ذخیره شده را بازیابی کرده و الگوی مربوطه را از طریق LEDهای مادون قرمز ارسال می‌کند؛ به این ترتیب، دستگاه می تواند نقش یک واسط هوشمند برای دریافت و بازپخش فرمان های کنترل از راه دور مادون قرمز را ایفا کند. برای پیاده‌سازی قابلیت دریافت و ارسال سیگنال های IR از کتابخانه IRremoteESP8266 استفاده شده است.

### 3-3-4- سیستم هشدار و نمایش وضعیت

برای ایجاد هشدار صوتی در سامانه از یک Active Buzzer استفاده شده است که ورودی آن به GPIO19 متصل شده است. فعال سازی بازر توسط Firmware و بر اساس شرایط تعریف شده در منطق سیستم انجام می‌شود؛ برای مثال، در صورت عبور مقدار خوانده شده از حسگر MQ-2 از آستانه تعیین‌شده یا در صورت تشخیص حرکت هنگامی که قابلیت هشدار حرکت فعال باشد، ESP32 می تواند بازر را فعال کرده و هشدار صوتی ایجاد کند. وضعیت هشدار نیز همزمان می تواند از طریق MQTT به داشبورد ارسال شود تا کاربر علاوه بر دریافت هشدار محلی، وضعیت دستگاه را از طریق رابط کاربری نیز مشاهده کند.

به منظور ارائه بازخورد بصری از وضعیت عملکرد دستگاه نیز یک LED وضعیت در نظر گرفته شده است. این LED به GPIO25 متصل شده و توسط Firmware برای نمایش وضعیت فعالیت سیستم و همچنین نمایش برخی رویدادهای مهم مانند دریافت یا ارسال سیگنال های RF و IR مورد استفاده قرار می گیرد. استفاده از LED وضعیت باعث می‌شود کاربر بتواند بدون نیاز به مشاهده داشبورد یا اتصال به شبکه، برخی وضعیت های عملیاتی دستگاه را به صورت مستقیم مشاهده کند.

###### جدول (3-1) پایه های ESP32

ردیف | تجهیز | پایه ESP32 | نوع ورودی/خروجی
۱ | DHT11 | GPIO15 | ورودی دیجیتال
۲ | MQ-2 Heater | GPIO26 | خروجی دیجیتال
۳ | MQ-2 ADC | GPIO33 | ورودی آنالوگ
۴ | LDR ADC | GPIO32 | ورودی آنالوگ
۵ | PIR | GPIO13 | ورودی دیجیتال
۶ | RF 315MHz Receiver | GPIO22 | ورودی دیجیتال
۷ | RF 315MHz Transmitter | GPIO23 | خروجی دیجیتال
۸ | RF 433MHz Receiver | GPIO14 | ورودی دیجیتال
۹ | RF 433 MHz Transmitter | GPIO27 | خروجی دیجیتال
۱۰ | IR Receiver | GPIO17 | ورودی دیجیتال
۱۱ | IR LED | GPIO4 | خروجی دیجیتال
۱۲ | Buzzer | GPIO19 | خروجی دیجیتال
۱۳ | Status LED | GPIO25 | خروجی دیجیتال

## 3-4- طراحی نرم افزار و ساختار Firmware

Firmware سامانه بر روی ماژول ESP32-WROOM-32 و با استفاده از محیط توسعه PlatformIO و چارچوب Arduino پیاده سازی شده است. با توجه به تعدد وظایف سیستم و وجود بخش های مختلفی مانند مدیریت حسگرها، ارتباط شبکه، ارتباط MQTT، دریافت و ارسال سیگنال های RF و IR، مدیریت هشدار و ذخیره‌سازی اطلاعات، ساختار Firmware به صورت ماژولار طراحی شده است. در این ساختار، هر بخش از نرم افزار مسئولیت مشخصی دارد و وظایف سیستم میان ماژول های مختلف تقسیم شده اند؛ به همین دلیل، تغییر یا توسعه یک قابلیت می تواند با کمترین وابستگی به سایر قسمت ها انجام شود و فرایند بررسی، اشکال زدایی و نگهداری Firmware نیز ساده تر خواهد بود.

### 3-4-1- ساختار ماژولار Firmware

ماژول های مختلف Firmware بر اساس وظایف سیستم از یکدیگر تفکیک شده اند. ماژول main مسئول راه اندازی اولیه و کنترل جریان اصلی برنامه است و ماژول Sensors وظیفه هماهنگی و مدیریت دوره ای حسگرها و رویداد های محیطی را بر عهده دارد. در بخش حسگرها نیز ماژول های اختصاصی DHT، MQ-2، LDR و PIR به ترتیب برای دریافت اطلاعات دما و رطوبت، پایش دود و گاز، اندازه گیری شدت نور و تشخیص حرکت مورد استفاده قرار گرفته اند. ماژول MQTT وظیفه برقراری ارتباط با MQTT Broker و مدیریت ارسال و دریافت پیام ها را بر عهده دارد، در حالی که ماژول های RF و IR برای دریافت، پردازش و ارسال مجدد سیگنال های فرکانس رادیویی و مادون قرمز استفاده می شوند. همچنین ماژول Alarm وضعیت هشدار و عملکرد بازر را مدیریت کرده، ماژول LED مسئول کنترل LED وضعیت است و Provisioning[^12] فرایند دریافت و تنظیم اطلاعات WiFi و MQTT را مدیریت می کند. برای ذخیره و بازیابی اطلاعات نیز ماژول Memory با سیستم فایل LittleFS در ارتباط بوده و ماژول Serial برای دریافت، پردازش و نمایش فرمان ها و اطلاعات از طریق ارتباط سریال مورد استفاده قرار گرفته است. در نهایت، پارامتر ها و تنظیمات ثابت مورد نیاز سیستم در ماژول Config نگهداری می شوند.

###### جدول (3-1) وظیفه ماژول های Firmware

ماژول | وظیفه
main | راه اندازی و کنترل جریان اصلی برنامه
Sensors | مدیریت دوره ای حسگر ها و رویداد های محیطی
DHT | دریافت دما و رطوبت
MQ-2 | دریافت مقدار گاز و دود
LDR | دریافت مقدار نور
PIR | تشخیص حرکت
MQTT | برقراری ارتباط با Broker و ارسال و دریافت پیام
RF | دریافت و ارسال سیگنال های RF
IR | دریافت و ارسال سیگنال های مادون قرمز
Alarm | مدیریت وضعیت هشدار و بازر
LED | مدیریت LED وضعیت
Provisioning | پیکربندی WiFi و MQTT
Memory | ذخیره و بازیابی اطلاعات در LittleFS
Serial | چاپ و دریافت و پردازش فرمان های متنی
Config | نگهداری تنظیمات و پارامتر های ثابت

### 3-4-2- راه اندازی و اجرای اصلی سیستم

پس از روشن شدن ESP32، برنامه وارد تابع setup() می‌شود که وظیفه آماده سازی اولیه اجزای مختلف سامانه را بر عهده دارد. در مرحله نخست، ارتباط سریال برای نمایش اطلاعات راه اندازی و دریافت فرمان های احتمالی برقرار می‌شود و سپس تنظیمات و پارامتر های موردنیاز سیستم از حافظه خوانده می شوند. در صورتی که اطلاعات موردنیاز شبکه WiFi و MQTT موجود نباشند یا نیاز به پیکربندی مجدد وجود داشته باشد، فرآیند Provisioning اجرا شده و پورتال تنظیمات برای دریافت اطلاعات شبکه و مشخصات MQTT در اختیار کاربر قرار می گیرد. پس از تکمیل پیکربندی، حسگرها و ماژول های ارتباطی موردنیاز راه اندازی شده و سیستم تلاش می کند ابتدا به شبکه WiFi و سپس به MQTT Broker متصل شود. پس از تکمیل موفقیت آمیز این مراحل، سیستم آماده ورود به چرخه اصلی اجرای برنامه خواهد بود.

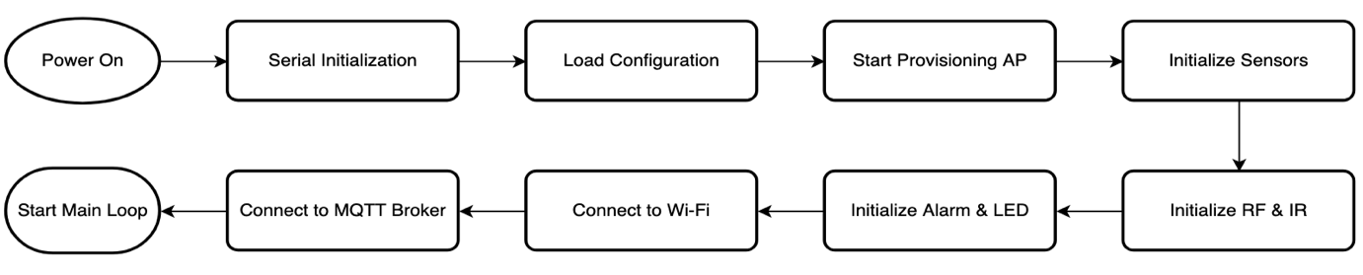
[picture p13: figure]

###### شکل (3-1) روند راه اندازی سیستم

پس از پایان عملیات راه اندازی، برنامه وارد تابع loop() می‌شود. این تابع به صورت مداوم اجرا شده و وظایف اصلی سامانه را مدیریت می‌کند. در هر چرخه، وضعیت ارتباط سریال و MQTT بررسی شده و در صورت دریافت فرمان جدید، پیام مربوطه پردازش می شود؛ سپس ماژول مدیریت حسگرها وضعیت حسگر های مختلف را بررسی کرده و در صورت رسیدن زمان نمونه برداری، مقادیر جدید را دریافت می کند. اطلاعات حاصل از حسگرها پس از پردازش در Topic های مربوط به MQTT منتشر می‌شوند و رویداد هایی مانند تشخیص حرکت یا عبور مقدار MQ-2 از آستانه تعیین شده نیز در همین فرایند بررسی و مدیریت می شوند. ساختار اجرای برنامه به گونه ای طراحی شده است که عملیات مختلف بدون توقف طولانی در یک بخش انجام شوند و اختلال در ارتباط شبکه، تا حد امکان موجب توقف عملکرد های محلی دستگاه نشود.

###### شکل (3-2) روند اجرای حلقه اصلی سیستم

### 3-4-3- مدیریت حسگرها و منطق هشدار

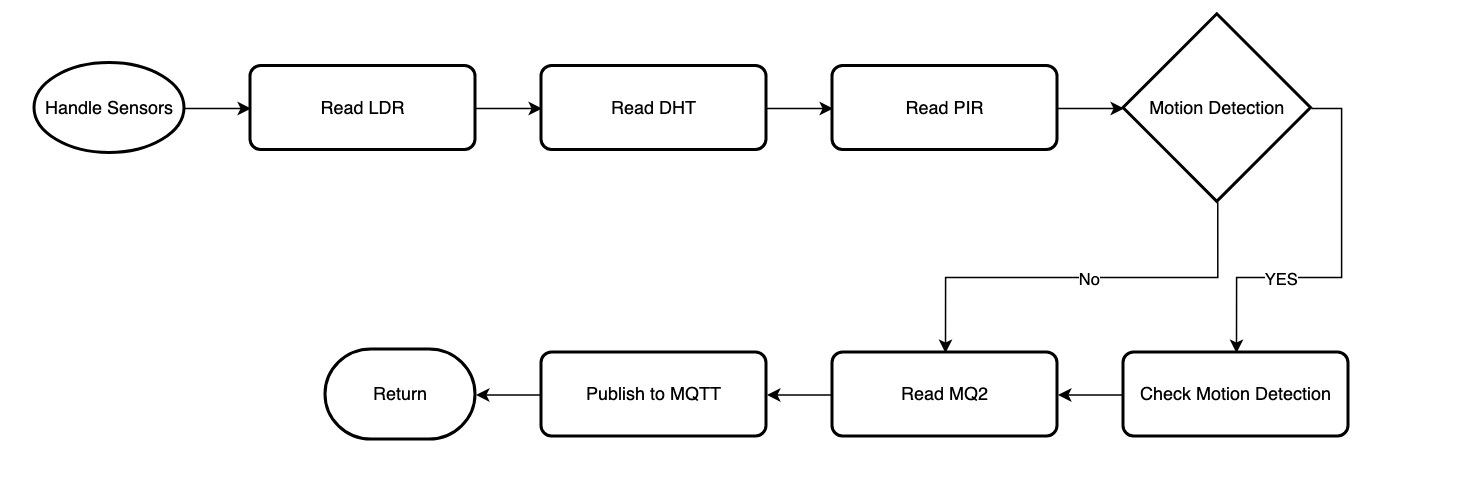
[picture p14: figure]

###### شکل (3-1) روند مدیریت حسگر ها

مدیریت حسگر های محیطی توسط ماژول Sensors انجام می شود و این ماژول نقش هماهنگ کننده میان درایور های مربوط به DHT11، MQ-2، LDR و PIR را بر عهده دارد. اطلاعات حسگرها در بازه های زمانی مشخص دریافت شده و پس از پردازش، مقدار هر حسگر در Topic مربوطه از طریق MQTT منتشر می شود. در نسخه فعلی Firmware، بازه زمانی اصلی برای نمونه برداری و انتشار اطلاعات حسگرها ۱۰ ثانیه در نظر گرفته شده است. این روش باعث می شود داده های محیطی به صورت دوره ای بروزرسانی شوند، در حالی که پردازش مداوم و غیرضروری حسگرها کاهش پیدا می کند.

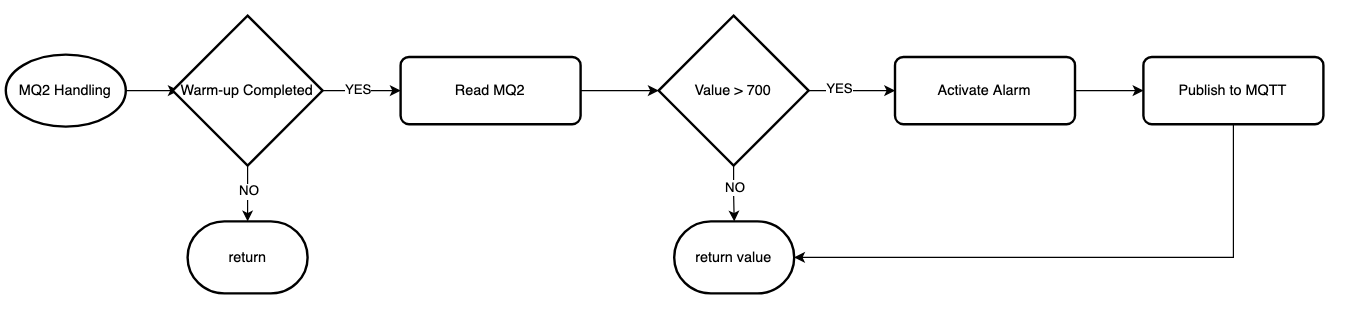
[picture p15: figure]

###### شکل (3-2) روند مدیریت حسگر MQ-2

در مورد حسگر MQ-2، به دلیل نیاز این حسگر به پیش گرمایش، Firmware پس از راه اندازی دستگاه یک دوره اولیه را برای آماده سازی آن در نظر می گیرد و تا پایان این دوره مقدار حسگر به عنوان داده قابل اتکا برای تصمیم گیری هشدار استفاده نمی شود. پس از پایان زمان پیش گرمایش، خروجی آنالوگ MQ-2 توسط ADC خوانده شده و مقدار به دست آمده علاوه بر انتشار از طریق MQTT، با آستانه تعیین شده در Firmware مقایسه می شود. در نسخه فعلی پروژه، زمان پیش گرمایش اولیه به دلیل محدودیت زمانی آزمایش ها ۵ دقیقه و مقدار آستانه ۷۰۰ در نظر گرفته شده است. در صورت عبور مقدار خوانده شده از این آستانه، ماژول Alarm فعال شده و وضعیت هشدار علاوه بر فعالسازی بازر، از طریق MQTT نیز به داشبورد ارسال می شود. لازم به ذکر است که این مقادیر با توجه به شرایط آزمایش و هدف نمونه اولیه انتخاب شده اند و مقدار مناسب آستانه MQ-2 در یک محیط واقعی باید بر اساس شرایط محیط، کالیبراسیون حسگر و آزمون های عملی تعیین شود.

دما و رطوبت محیط توسط حسگر DHT11 اندازه گیری می شوند و داده های آن در فواصل زمانی تعیین شده توسط ماژول Sensors دریافت می شوند. برای ارتباط با این حسگر از کتابخانه Adafruit DHT استفاده شده است و Firmware با استفاده از توابع readTemperature() و readHumidity() به ترتیب مقدار دما و رطوبت نسبی را دریافت می کند. مقدار شدت نور نیز توسط LDR و ورودی ADC خوانده شده و مانند سایر داده های محیطی پس از پردازش در اختیار ماژول MQTT قرار می گیرد. حسگر PIR نیز به صورت دیجیتال بررسی شده و تغییر وضعیت خروجی آن به عنوان رویداد تشخیص حرکت در نظر گرفته می شود. قابلیت تشخیص حرکت در Firmware قابل فعال یا غیرفعال شدن است و این کار از طریق فرمان های motion on و motion off انجام می شود. در صورتی که قابلیت تشخیص حرکت فعال باشد و PIR وقوع حرکت را گزارش کند، رویداد مربوطه توسط سیستم پردازش شده و می تواند باعث فعال شدن وضعیت هشدار و ارسال پیام مربوطه به MQTT شود.

مدیریت وضعیت هشدار توسط ماژول Alarm انجام می شود و این ماژول مسئول کنترل Active Buzzer و تعیین وضعیت هشدار سیستم است. در پیاده‌سازی فعلی دو رویداد اصلی می‌توانند موجب فعال شدن هشدار شوند که شامل عبور مقدار MQ-2 از آستانه تعیین شده و تشخیص حرکت در صورت فعال بودن قابلیت تشخیص حرکت است. علاوه بر هشدار های خودکار، امکان کنترل مستقیم بازر نیز از طریق فرمان های buzzer on و buzzer off فراهم شده است. هنگامی که وضعیت هشدار فعال می شود، بازر بر اساس منطق زمانی تعریف شده توسط Firmware کنترل می شود. در نسخه فعلی چرخه زمانی فعال و غیرفعال شدن آن ۲ ثانیه در نظر گرفته شده است. این ساختار باعث می‌شود سیستم بتواند هم در واکنش به رویدادهای محیطی و هم در پاسخ به فرمان مستقیم کاربر، هشدار صوتی ایجاد کند.

## 3-5- طراحی ارتباط WiFi و MQTT

ارتباط شبکه ای سامانه بر پایه قابلیت WiFi داخلی ESP32 طراحی شده است و این ارتباط، مسیر اصلی تبادل اطلاعات میان دستگاه، MQTT Broker و داشبورد تحت وب را فراهم می‌کند. ESP32 پس از راه اندازی و دریافت تنظیمات شبکه، به شبکه WiFi موردنظر متصل شده و از طریق این ارتباط امکان ارسال اطلاعات حسگرها، وضعیت هشدار و سایر داده های سامانه به زیرساخت نرم افزاری را فراهم می کند. همچنین همین مسیر برای دریافت فرمان های کنترلی از سمت کاربر مورد استفاده قرار می گیرد؛ بنابراین ارتباط شبکه ای سیستم به صورت دوطرفه طراحی شده است.

### 3-5-1- پیکربندی و ارتباط WiFi

در سامانه حاضر از حالت WIFI_AP_STA استفاده شده است. در این حالت، ESP32 می تواند به صورت همزمان در نقش Station به شبکه WiFi موردنظر متصل شده و در کنار آن یک Access Point اختصاصی نیز ایجاد کند. این قابلیت در فرآیند Provisioning مورد استفاده قرار می گیرد و به دستگاه اجازه می دهد بدون نیاز به تغییر یا کامپایل مجدد Firmware، اطلاعات مربوط به شبکه WiFi و سایر تنظیمات موردنیاز را از کاربر دریافت کند. پس از انجام پیکربندی و برقراری اتصال به شبکه اصلی، ESP32 از ارتباط WiFi به عنوان مسیر ارتباطی خود با MQTT Broker استفاده می کند.

استفاده از این ساختار باعث شده است که فرآیند راه‌اندازی اولیه دستگاه از تنظیمات ثابت Firmware جدا شود و کاربر بتواند اطلاعات شبکه را در زمان راه اندازی یا در صورت نیاز در مراحل بعدی تغییر دهد. در نتیجه، دستگاه برای استفاده در شبکه های مختلف نیازی به تغییر کد برنامه نخواهد داشت و اطلاعات پیکربندی شده نیز می‌توانند در حافظه داخلی دستگاه ذخیره شده و در راه اندازی های بعدی مورد استفاده قرار گیرند.

### 3-5-2- ارتباط MQTT

برای تبادل اطلاعات میان ESP32، MQTT Broker و داشبورد تحت وب از پروتکل MQTT استفاده شده است. این پروتکل بر اساس مدل Publish/Subscribe عمل می کند و باعث می شود فرستنده و گیرنده پیام ها مستقیماً به یکدیگر وابسته نباشند. در این معماری، ESP32 اطلاعات حسگرها و وضعیت سیستم را در Topic های مشخص منتشر می کند و داشبورد یا سایر Client های متصل به Broker می‌توانند Topic های موردنظر را Subscribe کرده و پیام های مربوطه را دریافت کنند. از طرف دیگر، داشبورد می تواند فرمان های کنترلی را در Topic های مشخص منتشر کند و ESP32 با Subscribe کردن به این Topic ها، پیام های دریافت شده را پردازش و اجرا کند.

در این پروژه از broker.emqx.io به عنوان MQTT Broker استفاده شده است. برای جلوگیری از پراکندگی Topic ها و ایجاد یک ساختار منظم، یک Topic پایه با مقدار homeintelligence در نظر گرفته شده است و نام دستگاه نیز توسط کاربر تعیین می‌شود. بر این اساس، Topic های مختلف سامانه از یک ساختار مشترک پیروی می کنند و نوع داده یا عملکرد هر Topic از بخش انتهایی مسیر آن مشخص می‌شود. به صورت کلی می‌توان ساختار Topic را به صورت زیر در نظر گرفت:

homeintelligence / <device> / <subtopic>

برای اطلاعات حسگرها، هر نوع داده در یک Topic مجزا منتشر می شود تا دریافت و پردازش آن برای داشبورد و سایر Client ها ساده باشد. ساختار Topic های مربوط به حسگرهای اصلی سامانه در جدول زیر ارائه شده است

###### جدول (3-1) Topic های مربوط به حسگرها

Topic | داده
…/sensor/TEMP | دما
…/sensor/HUM | رطوبت
…/sensor/LDR | شدت نور
…/sensor/PIR | تشخیص حرکت
…/sensor/MQ2 | دود و گاز

در کنار اطلاعات حسگرها، برای اطلاع رسانی رویداد های مهم سیستم از Topic مربوط به هشدار با ساختار .../alarm استفاده شده است. این Topic برای ارسال پیام هایی که نشان دهنده وقوع یا تغییر وضعیت یک رویداد هشدار هستند مورد استفاده قرار می گیرد. برای مثال، در صورت عبور مقدار MQ-2 از آستانه تعیین شده، پیام MQ2 threshold exceed منتشر می شود و در صورت تشخیص حرکت نیز پیام Motion Detected به داشبورد ارسال می شود. همچنین تغییر وضعیت قابلیت تشخیص حرکت با پیام های Motion ON و Motion OFF اطلاع رسانی می شود.

برای دریافت فرمان های کنترلی از سمت داشبورد نیز Topic با ساختار .../command در نظر گرفته شده است. Firmware این Topic را Subscribe کرده و در صورت دریافت پیام جدید، آن را به بخش مدیریت فرمان منتقل می کند. این بخش بر اساس محتوای پیام، عملیات متناظر را شناسایی و اجرا می کند. به این ترتیب، قابلیت هایی مانند فعال یا غیرفعال کردن تشخیص حرکت، کنترل بازر و سایر عملیات کنترلی می توانند از طریق یک مسیر ارتباطی مشخص مدیریت شوند.

علاوه بر داده های حسگر و فرمان های کنترلی، سامانه باید فهرست سیگنال های ذخیره شده RF و IR را نیز در اختیار داشبورد قرار دهد. برای این منظور از Topic های .../RF/list و .../IR/list استفاده شده است. پیام های منتشر شده در این Topic ها در قالب JSON ارسال می شوند و شامل اطلاعات مربوط به سیگنال های ذخیره شده هستند. داشبورد با دریافت این اطلاعات می تواند فهرست سیگنال های موجود را به کاربر نمایش داده و امکان انتخاب سیگنال موردنظر برای انجام عملیات بعدی، مانند ارسال مجدد یا مدیریت اطلاعات ذخیره شده، را فراهم کند.

## 3-6- طراحی سیستم RF

یکی از قابلیت های اصلی سامانه، امکان دریافت، ذخیره سازی و بازپخش سیگنال های رادیویی در دو باند فرکانسی ۳۱۵ و ۴۳۳ مگاهرتز است. با توجه به اینکه گیرنده ها و فرستنده های مورد استفاده در هر باند به صورت تک فرکانس عمل می کنند، برای هر یک از این دو باند یک مسیر مستقل برای دریافت و ارسال سیگنال در نظر گرفته شده است. به این ترتیب، سامانه می تواند سیگنال های مربوط به هر دو باند را دریافت کرده و پس از شناسایی و ذخیره اطلاعات آنها، در زمان موردنیاز سیگنال را از طریق فرستنده متناسب با باند فرکانسی آن بازپخش کند. مدیریت ارتباط با ماژول های RF و دریافت و ارسال سیگنال ها در Firmware توسط کتابخانه RCSwitch انجام شده است.

### 3-6-1- دریافت و ذخیره سازی سیگنال RF

فرایند دریافت سیگنال RF از طریق فرمان rf rx <name> آغاز می شود که در آن <name> نامی است که کاربر برای سیگنال موردنظر تعیین می کند. پس از اجرای این فرمان، Firmware هر دو مسیر دریافت RF مربوط به باندهای ۳۱۵ و ۴۳۳ مگاهرتز را فعال کرده و وضعیت گیرنده ها را بررسی می‌کند. هنگامی که یک سیگنال توسط یکی از گیرنده ها دریافت شود، اطلاعات مربوط به سیگنال توسط کتابخانه RCSwitch استخراج شده و باند فرکانسی مربوط به گیرنده ای که سیگنال را دریافت کرده است نیز مشخص می شود. این اطلاعات سپس در قالب ساختار مورد استفاده Firmware قرار گرفته و با نام تعیین شده توسط کاربر در حافظه دائمی دستگاه ذخیره می شود.

اطلاعات سیگنال های RF در فایل /rf_signals.json در سیستم فایل LittleFS نگهداری می شوند. استفاده از حافظه دائمی باعث می شود اطلاعات سیگنال های ذخیره شده با خاموش یا راه اندازی مجدد ESP32 از بین نروند و دستگاه بتواند پس از راه اندازی مجدد، اطلاعات قبلی را از حافظه بازیابی کند. همچنین ذخیره نام سیگنال در کنار اطلاعات مربوط به باند فرکانسی باعث می‌شود در هنگام بازپخش، سیستم بتواند بدون دریافت مجدد اطلاعات از کاربر، فرستنده مناسب را انتخاب کند.

### 3-6-2- بازپخش و مدیریت سیگنال RF

برای بازپخش یک سیگنال ذخیره شده از فرمان rf tx <name> استفاده می شود. پس از دریافت این فرمان، Firmware نام سیگنال موردنظر را در اطلاعات ذخیره شده جست و جو کرده و پس از بازیابی اطلاعات آن، باند فرکانسی مربوط به سیگنال را بررسی می کند. سپس بر اساس باند ثبت شده، فرستنده مناسب انتخاب شده و اطلاعات سیگنال از طریق آن ارسال می شود. در نتیجه، کاربر هنگام بازپخش سیگنال نیازی به مشخص کردن فرکانس ندارد و انتخاب مسیر ارسال به صورت خودکار توسط Firmware انجام می شود.

برای مدیریت سیگنال های ذخیره شده نیز فرمان های rf list و rf del <name> در نظر گرفته شده اند. فرمان rf list فهرست سیگنال های موجود در حافظه را نمایش داده و اطلاعات این فهرست را از طریق MQTT نیز در اختیار داشبورد قرار می دهد تا کاربر بتواند سیگنال های ذخیره شده را مشاهده و انتخاب کند. فرمان rf del <name> نیز برای حذف یک سیگنال مشخص از حافظه استفاده می‌شود.

## 3-7- طراحی سیستم مادون قرمز

سیستم مادون قرمز سامانه از دو بخش اصلی گیرنده و فرستنده تشکیل شده است و وظیفه آن دریافت، پردازش، ذخیره سازی و بازپخش فرمان های مادون قرمز مورد استفاده در تجهیزات مختلف است. در این بخش، گیرنده مادون قرمز سیگنال ارسال شده توسط کنترل های از راه دور را دریافت کرده و اطلاعات آن توسط ESP32 پردازش می شود؛ سپس سیگنال دریافت شده با یک نام مشخص در حافظه دائمی دستگاه ذخیره شده و در زمان موردنیاز می توان آن را بازیابی و از طریق LED های مادون قرمز بازپخش کرد. برای پیاده سازی فرایند دریافت و ارسال سیگنال های IR از کتابخانه IRremoteESP8266 استفاده شده است که امکان کار با تعدادی از پروتکل های رایج کنترل از راه دور را فراهم می کند.

### 3-7-1- دریافت و ذخیره سازی سیگنال IR

فرایند دریافت سیگنال مادون قرمز با اجرای فرمان ir rx <name> آغاز می شود که در آن <name> نامی است که کاربر برای سیگنال موردنظر تعیین می کند. پس از اجرای فرمان، Firmware وارد حالت دریافت شده و منتظر دریافت یک سیگنال مادون قرمز می ماند. با دریافت سیگنال، اطلاعات مربوط به آن توسط گیرنده دریافت شده و کتابخانه IRremoteESP8266 داده های مربوط به پروتکل و محتوای سیگنال را استخراج و برای پردازش در اختیار Firmware قرار می دهد. سامانه قادر به شناسایی و پردازش تعدادی از پروتکل های رایج مانند NEC، SONY، SAMSUNG و PANASONIC است و در صورتی که پروتکل دریافت شده توسط کتابخانه شناسایی یا پشتیبانی نشود، اطلاعات خام سیگنال نیز قابل دریافت و ذخیره سازی خواهد بود.

پس از دریافت سیگنال، اطلاعات آن با نام تعیین شده توسط کاربر در حافظه دائمی دستگاه و در قالب JSON ذخیره می‌شود. اطلاعات مربوط به سیگنال های IR در فایل /ir_signals.json در سیستم فایل LittleFS نگهداری می شوند. ذخیره‌سازی در حافظه دائمی باعث می شود سیگنال های ثبت شده پس از خاموش و روشن شدن دستگاه نیز حفظ شوند و در راه اندازی های بعدی امکان بازیابی و استفاده مجدد از آنها وجود داشته باشد.

### 3-7-2- بازپخش و مدیریت سیگنال IR

برای بازپخش یک سیگنال ذخیره شده از فرمان ir tx <name> استفاده می شود. پس از دریافت این فرمان، Firmware اطلاعات سیگنال موردنظر را از حافظه بازیابی کرده و بر اساس اطلاعات ذخیره شده، روش مناسب برای ارسال آن را انتخاب می کند. در صورتی که پروتکل سیگنال توسط کتابخانه پشتیبانی شود، داده های مربوط به آن با استفاده از پروتکل شناسایی شده تولید و از طریق LED های مادون قرمز ارسال می شوند؛ در غیر این صورت، اطلاعات خام ذخیره شده مورد استفاده قرار گرفته و سیگنال به صورت خام بازپخش می شود. به این ترتیب، سامانه علاوه بر پشتیبانی از پروتکل های شناخته شده، امکان ذخیره و بازپخش سیگنال هایی را که پروتکل آنها قابل شناسایی نیست نیز فراهم می کند.

برای مدیریت سیگنال های ذخیره شده نیز دو فرمان ir list و ir del <name> در نظر گرفته شده است. فرمان ir list فهرست سیگنال های موجود در حافظه را نمایش داده و اطلاعات مربوط به این فهرست را از طریق MQTT نیز در اختیار داشبورد قرار می‌دهد تا کاربر بتواند سیگنال های ثبت شده را مشاهده و انتخاب کند. فرمان ir del <name> نیز برای حذف یک سیگنال مشخص از حافظه استفاده می‌شود.

## 3-8- طراحی سیستم ذخیره سازی

برای ذخیره سازی اطلاعاتی که باید پس از خاموش و روشن شدن دستگاه نیز حفظ شوند، از سیستم فایل LittleFS موجود در ESP32 استفاده شده است. استفاده از این سیستم فایل امکان ذخیره سازی اطلاعات به صورت دائمی و بدون نیاز به حافظه خارجی را فراهم می کند و باعث می شود تنظیمات دستگاه و اطلاعات سیگنال های ثبت شده پس از راه اندازی مجدد نیز قابل بازیابی باشند. در این پروژه اطلاعات دائمی سامانه در قالب فایل های JSON سازمان دهی شده است تا ساختار داده ها ساده، قابل خواندن و قابل پردازش توسط Firmware باشد.

در مجموع، چهار فایل اصلی برای نگهداری اطلاعات دائمی سامانه در نظر گرفته شده است که هر یک وظیفه مشخصی بر عهده دارند. فایل provisioning.json برای نگهداری اطلاعات مربوط به شبکه WiFi و MQTT، فایل settings.json برای تنظیمات داخلی دستگاه، فایل rf_signals.json برای نگهداری سیگنال های RF و فایل ir_signals.json برای نگهداری سیگنال های مادون قرمز استفاده می‌شود.

### 3-8-1- ذخیره تنظیمات و اطلاعات دستگاه

اطلاعات مربوط به پیکربندی شبکه در فایل provisioning.json و به صورت JSON ذخیره می شوند. این اطلاعات شامل SSID و رمز عبور شبکه WiFi، آدرس و پورت MQTT Broker، نام کاربری و رمز عبور MQTT در صورت استفاده و نام اختصاصی دستگاه است. نگهداری این اطلاعات در حافظه دائمی باعث می شود دستگاه پس از راه اندازی مجدد بتواند تنظیمات قبلی را بازیابی کرده و بدون نیاز به وارد کردن مجدد اطلاعات شبکه، فرایند اتصال را انجام دهد.

تنظیمات مربوط به وضعیت داخلی دستگاه نیز در فایل settings.json ذخیره می شوند. در نسخه فعلی پروژه، یکی از مهم ترین اطلاعات این فایل وضعیت فعال یا غیرفعال بودن قابلیت تشخیص حرکت است. به این ترتیب، تنظیماتی که باید پس از خاموش و روشن شدن دستگاه حفظ شوند، از اطلاعات مربوط به پیکربندی شبکه و اطلاعات سیگنال ها جدا نگهداری شده و هر گروه از داده ها فایل مخصوص به خود را دارد.

### 3-8-2- ذخیره سازی سیگنال RF و IR

اطلاعات مربوط به سیگنال های RF در فایل rf_signals.json ذخیره می شوند. برای هر سیگنال، علاوه بر نام تعیین شده توسط کاربر، اطلاعات موردنیاز برای بازپخش آن نیز در حافظه نگهداری می شود. این اطلاعات شامل کد سیگنال، تعداد بیت، پروتکل، طول پالس و باند فرکانسی است. ذخیره باند فرکانسی در کنار سایر اطلاعات سیگنال اهمیت دارد، زیرا سیستم هنگام بازپخش می تواند بر اساس این مقدار، فرستنده مناسب مربوط به باند ۳۱۵ یا ۴۳۳ مگاهرتز را به صورت خودکار انتخاب کند.

سیگنال های مادون قرمز نیز در فایل ir_signals.json ذخیره می شوند. اطلاعات اصلی هر سیگنال شامل نام سیگنال، پروتکل، کد سیگنال و تعداد بیت است و در مواردی که پروتکل سیگنال قابل شناسایی یا پشتیبانی نباشد، اطلاعات خام سیگنال نیز در ساختار ذخیره‌سازی نگهداری می شود تا امکان بازپخش آن در آینده وجود داشته باشد. این روش باعث شده است که سیستم تنها به پروتکل های شناخته شده وابسته نباشد و بتواند سیگنال های خام را نیز برای استفاده مجدد ذخیره کند.

## 3-9- طراحی سیستم Provisioning و Captive Portal

یکی از قابلیت های نرم‌افزاری سامانه، امکان پیکربندی اطلاعات مربوط به شبکه WiFi و MQTT بدون نیاز به تغییر یا کامپایل مجدد Firmware است. این قابلیت با استفاده از مکانیزم Provisioning پیاده سازی شده است و به کاربر اجازه می دهد در زمان راه اندازی دستگاه، اطلاعات موردنیاز برای اتصال به شبکه و MQTT Broker را از طریق یک رابط تحت وب وارد و ذخیره کند. برای اجرای این فرآیند، ESP32 در حالت WIFI_AP_STA قرار می گیرد؛ به این ترتیب دستگاه علاوه بر تلاش برای اتصال به شبکه WiFi تنظیم شده، یک Access Point اختصاصی نیز ایجاد می کند که برای دسترسی کاربر به بخش پیکربندی مورد استفاده قرار می گیرد.

###### جدول (3-1) مشخصات AP

مشخصه | مقدار
SSID | Intelligence_Setup
Password | 12345678
IP | 192.168.4.1

پس از اتصال کاربر به Access Point دستگاه، یک Captive Portal در اختیار وی قرار می گیرد که به عنوان رابط پیکربندی سامانه عمل می کند. این صفحه امکان وارد کردن اطلاعات موردنیاز برای اتصال ESP32 به شبکه WiFi و MQTT Broker را فراهم می‌کند و کاربر می تواند اطلاعاتی مانند نام شبکه، رمز عبور WiFi، آدرس و پورت MQTT Broker و در صورت نیاز اطلاعات احراز هویت MQTT را در آن وارد کند. پس از ارسال و تأیید اطلاعات، Firmware داده های دریافت شده را در قالب JSON در فایل provisioning.json موجود در سیستم فایل LittleFS ذخیره کرده و سپس دستگاه را راه‌اندازی مجدد می‌کند.

## 3-10- طراحی Web Dashboard

داشبورد تحت وب سامانه با هدف نمایش اطلاعات محیطی، مشاهده وضعیت عملکرد دستگاه و ارسال فرمان های کنترلی به ESP32 طراحی شده است. این داشبورد به صورت Serverless پیاده‌سازی شده و برای تبادل اطلاعات مستقیماً از طریق WebSocket به MQTT Broker متصل می‌شود؛ بنابراین برای ارتباط میان رابط کاربر و ESP32 نیازی به ایجاد یک سرور واسط اختصاصی وجود ندارد. از آنجا که مرورگر های وب به صورت مستقیم از ارتباط MQTT بر بستر TCP پشتیبانی نمی کنند، MQTT Broker مورد استفاده باید قابلیت WebSocket را فعال کرده باشد تا داشبورد بتواند از طریق این پروتکل به Broker متصل شده و پیام های MQTT را دریافت و ارسال کند.

پس از برقراری اتصال، داشبورد Topic های مربوط به اطلاعات حسگرها را Subscribe کرده و داده های منتشر شده توسط ESP32 را به صورت لحظه ای دریافت می کند. اطلاعات مربوط به دما، رطوبت، شدت نور، وضعیت تشخیص حرکت و مقدار مربوط به دود و گاز در بخش های مربوطه نمایش داده می شوند و با دریافت هر پیام جدید، مقدار نمایش داده شده در رابط کاربر بروزرسانی می شود؛ بنابراین برای مشاهده تغییرات نیازی به Refresh کردن صفحه وجود ندارد. علاوه بر اطلاعات حسگرها، داشبورد پیام های مربوط به وضعیت هشدار را نیز دریافت کرده و در صورت وقوع رویداد هایی مانند عبور مقدار MQ-2 از آستانه تعیین شده یا تشخیص حرکت در حالت فعال، وضعیت هشدار را به کاربر نمایش می دهد.

داشبورد علاوه بر نمایش اطلاعات، امکان ارسال فرمان های کنترلی به ESP32 را نیز فراهم می کند. این فرمان ها از طریق MQTT و در Topic مربوط به .../command ارسال شده و پس از دریافت توسط ESP32، توسط بخش مدیریت فرمان پردازش و اجرا می شوند. فرمان های buzzer on و buzzer off برای کنترل بازر و فرمان های motion on و motion off برای فعال یا غیرفعال کردن قابلیت تشخیص حرکت مورد استفاده قرار می گیرند. همچنین فرمان های مربوط به مدیریت سیگنال های RF و فرمان های مربوط به سیستم مادون قرمز که امکان دریافت، بازپخش، حذف و مشاهده فهرست سیگنال های ذخیره شده را از طریق رابط کاربر فراهم می کند.

# فصل 4: پیاده سازی سامانه

در این فصل، فرایند پیاده سازی سامانه تشریح می شود. پس از بررسی مبانی نظری و طراحی سامانه در فصل های پیشین، در این فصل نحوه تبدیل طراحی ارائه شده به یک سامانه عملیاتی مورد بررسی قرار می گیرد. پیاده سازی انجام شده شامل دو بخش اصلی Firmware دستگاه و رابط کاربری تحت وب است.

Firmware بر روی برد ESP32 و با استفاده از چارچوب Arduino توسعه داده شده و وظیفه مدیریت حسگرها، پردازش داده های دریافتی، کنترل سیستم هشدار، دریافت و ارسال سیگنال های RF و IR، مدیریت ارتباط WiFi و MQTT و همچنین ذخیره سازی اطلاعات را بر عهده دارد. در بخش سخت افزاری، ESP32 به مجموعه ای از حسگرها و تجهیزات جانبی شامل حسگر دما و رطوبت DHT11، حسگر گاز و دود MQ-2، حسگر نور مبتنی بر LDR، حسگر تشخیص حرکت PIR، گیرنده و فرستنده RF در باند های ۳۱۵ و ۴۳۳ مگاهرتز، گیرنده و فرستنده مادون قرمز و بازر متصل شده است. اطلاعات دریافت شده از حسگر ها توسط ESP32 پردازش شده و در فواصل زمانی مشخص فرستاده می شود. در بخش ارتباطی دستگاه با استفاده از WiFi به شبکه متصل شده و برای تبادل داده و دریافت فرمان های کنترلی از پروتکل MQTT استفاده می کند. MQTT Broker مورد استفاده در پیاده سازی نهایی پروژه، سرویس عمومی broker.emqx.io است. همچنین برای پیکربندی اولیه و تغییر تنظیمات شبکه، زیرسامانه مبتنی بر Access Point و Captive Portal در Firmware پیاده سازی شده است. یکی دیگر از قابلیت های اصلی سامانه، امکان دریافت، ذخیره و بازپخش سیگنال های RF و IR است. این قابلیت دستگاه را از یک سامانه صرفا نظارتی به یک واسط ارتباطی میان تجهیزات الکترونیکی و زیرساخت هوشمند تبدیل می کند. در نهایت، یک Web Dashboard برای مشاهده داده های حسگرها، دریافت هشدار ها و ارسال فرمان های کنترلی طراحی شده است. این داشبورد مستقیما با MQTT Broker ارتباط برقرار کرده و امکان تعامل کاربر با دستگاه را بدون نیاز به یک Backend اختصاصی فراهم می کند.

## 4-1- محیط و ابزار های توسعه

توسعه و پیاده‌سازی Firmware سامانه بر روی ماژول ESP32-WROOM-32 با استفاده از محیط توسعه PlatformIO و چارچوب نرم افزاری Arduino انجام شده است. تنظیمات مربوط به محیط توسعه، مشخصات سخت افزاری برد، Framework مورد استفاده، سرعت ارتباط سریال، سیستم فایل و کتابخانه های موردنیاز پروژه در فایل platformio.ini تعریف شده اند. این فایل به عنوان فایل اصلی پیکربندی پروژه در PlatformIO، محیط موردنیاز برای ساخت و بارگذاری Firmware را مشخص می‌کند و باعث می‌شود وابستگی های نرم‌افزاری و تنظیمات مربوط به برد به صورت یکپارچه در پروژه تعریف شوند. در این پروژه از پلتفرم espressif32 برای توسعه نرم‌افزار مربوط به خانواده ESP32 استفاده شده و Framework انتخاب شده نیز Arduino است. پارامتر platform پلتفرم مورد استفاده را مشخص می‌کند و پارامتر board نیز تنظیمات مربوط به برد را تعیین می‌کند که در پروژه حاضر با توجه به استفاده از برد عمومی ESP32 DevKit، مقدار esp32dev برای آن در نظر گرفته شده است.

برای مشاهده پیام های خروجی Firmware و بررسی وضعیت عملکرد دستگاه، ارتباط سریال با سرعت 115200 baud تنظیم شده است. این ارتباط در مراحل توسعه، آزمایش و خطایابی سامانه نقش مهمی دارد و امکان مشاهده اطلاعات مربوط به راه‌اندازی اولیه دستگاه، وضعیت حسگرها، فرآیند اتصال به شبکه WiFi و MQTT Broker، دریافت و اجرای فرمان ها و همچنین پیام های مربوط به عملکرد بخش های مختلف Firmware را فراهم می کند. استفاده از Serial Monitor باعث می شود در زمان توسعه بتوان وضعیت داخلی سیستم را بدون نیاز به ابزار های خارجی بررسی کرد و در صورت بروز خطا در بخش هایی مانند اتصال شبکه، دریافت سیگنال های RF و IR یا اجرای فرمان ها، اطلاعات لازم برای تشخیص مشکل در اختیار توسعه دهنده قرار گیرد.

در بخش ذخیره سازی اطلاعات دائمی نیز از سیستم فایل LittleFS استفاده شده است که امکان استفاده از حافظه داخلی ESP32 برای نگهداری داده هایی را فراهم می کند که باید پس از خاموش و روشن شدن دستگاه همچنان باقی بمانند. در این پروژه از LittleFS برای ذخیره اطلاعات مربوط به تنظیمات Provisioning، تنظیمات داخلی دستگاه و همچنین سیگنال های ذخیره شده RF و IR استفاده شده است. فایل های مربوط به این اطلاعات در زمان راه‌اندازی توسط Firmware بررسی و در صورت وجود، اطلاعات موردنیاز از آنها بازیابی می شود؛ بنابراین تغییر وضعیت تغذیه یا راه اندازی مجدد دستگاه موجب از بین رفتن اطلاعات ذخیره شده نخواهد شد.

پس از آماده سازی محیط توسعه و نصب کتابخانه ها و وابستگی های تعریف شده در فایل platformio.ini، فرایند ساخت Firmware توسط PlatformIO انجام می شود. در این مرحله کد های منبع پروژه به همراه کتابخانه های مورد استفاده کامپایل شده و فایل اجرایی مناسب برای ESP32 تولید می شود و پس از موفقیت آمیز بودن فرایند ساخت، Firmware از طریق رابط ارتباطی مناسب بر روی برد بارگذاری می شود. پس از بارگذاری نیز می‌توان با استفاده از Serial Monitor پیام های خروجی دستگاه را مشاهده و عملکرد بخش های مختلف سیستم را بررسی کرد. در نتیجه، محیط توسعه پروژه علاوه بر فراهم کردن ابزار های موردنیاز برای برنامه نویسی و ساخت Firmware، امکانات لازم برای مدیریت وابستگی ها، بارگذاری برنامه، ذخیره سازی اطلاعات و بررسی عملکرد سامانه در مرحله توسعه و آزمایش را نیز در اختیار قرار می دهد.

###### شکل (4-1) روند ساخت و بارگذاری Firmware

## 4-2- پیاده سازی سخت افزار

در پیاده سازی سخت افزاری سامانه، هر یک از حسگرها و تجهیزات جانبی به یکی از پایه های GPIO ماژول ESP32 متصل شده و ارتباط میان سخت افزار و Firmware بر اساس این نگاشت انجام می شود. به منظور جلوگیری از پراکندگی شماره پایه ها در بخش های مختلف برنامه و همچنین ساده تر شدن فرایند تغییر اتصالات در صورت نیاز، تمامی پایه های مورد استفاده در فایل پیکربندی config.h تعریف شده اند؛ بنابراین هر ماژول نرم افزاری به جای استفاده مستقیم از شماره پایه، از ثابت تعریف شده مربوط به آن تجهیز استفاده می کند و در نتیجه تغییر یک اتصال سخت افزاری تنها با اصلاح مقدار مربوطه در فایل پیکربندی امکان پذیر خواهد بود. نگاشت کامل پایه های مورد استفاده در ‏جدول (3-1) ارائه شده است

### 4-2-1- پیاده سازی حسگر های محیطی

برای اندازه گیری دما و رطوبت محیط از حسگر DHT11 و کتابخانه Adafruit DHT استفاده شده است. در زمان راه اندازی Firmware، تابع setupDHT() فراخوانی شده و با اجرای dht.begin() ارتباط نرم افزار با حسگر آماده می شود. پس از راه اندازی، اطلاعات دما و رطوبت توسط توابع جداگانه دریافت می شوند و در صورت نامعتبر بودن مقدار خوانده شده، پیام خطا در Serial Monitor نمایش داده می‌شود.

void setupDHT()

{

dht.begin();

}

float readHumidity()

{

float input = dht.readHumidity();

if (isnan(input))

{

Serial.println("Failed to read humidity from DHT sensor");

}

return input;

}

float readTemperature()

{

float input = dht.readTemperature();

if (isnan(input))

{

Serial.println("Failed to read temperature from DHT sensor");

}

return input;

}

در این پیاده سازی، تابع setupDHT() تنها یک بار در مرحله راه اندازی اجرا می شود، در حالی که توابع readHumidity() و readTemperature() در زمان نمونه برداری حسگر فراخوانی شده و مقدار رطوبت و دمای اندازه گیری شده را بر می گردانند. استفاده از isnan() نیز باعث می شود در صورت عدم دریافت داده معتبر از حسگر، وضعیت خطا مشخص شده و از پردازش بی اطلاع یک مقدار نامعتبر جلوگیری شود.

برای اندازه گیری شدت نور محیط از ماژول LDR استفاده شده است که خروجی آن به ورودی آنالوگ ESP32 متصل شده و مقدار آن توسط ADC خوانده می شود. از آنجا که مقدار خروجی LDR به صورت ولتاژ آنالوگ است، برای تبدیل این مقدار به داده قابل پردازش توسط Firmware از تابع analogRead() استفاده شده است.

void setupLDR()

{

pinMode(LDR_PIN,INPUT);

}

int readLDR()

{

int input = analogRead(LDR_PIN);

return input;

}

تابع readLDR() با فراخوانی analogRead() مقدار ADC مربوط به پایه LDR_PIN را دریافت کرده و مقدار خام تبدیل شده را بر می گرداند. این مقدار در ادامه توسط ماژول مدیریت حسگرها مورد استفاده قرار گرفته و از طریق MQTT برای نمایش در داشبورد ارسال می شود.

برای تشخیص دود و برخی گازهای قابل اشتعال از حسگر MQ-2 استفاده شده است. خروجی آنالوگ حسگر به ورودی ADC متصل شده و مقدار آن به صورت یک مقدار دیجیتال توسط ESP32 خوانده می‌شود. از آنجا که مقدار خام حسگر به تنهایی نشان دهنده وقوع شرایط هشدار نیست، پس از دریافت مقدار ADC، مقدار آن با آستانه از پیش تعیین‌شده مقایسه می‌شود.

void setupMQ2()

{

pinMode(MQ2_PIN, INPUT);

}

int readMQ2()

{

return analogRead(MQ2_PIN);

}

bool checkThreshold(int value)

{

if (value > MQ2_THRESHOLD)

{

return true;

}

return false;

}

در تابع readMQ2() مقدار خروجی آنالوگ حسگر توسط ADC خوانده می شود و در تابع checkThreshold() مقدار دریافت شده با ثابت MQ2_THRESHOLD مقایسه می شود. در صورتی که مقدار اندازه گیری شده از آستانه تعیین شده بیشتر باشد، مقدار true بازگردانده شده و سیستم می تواند این وضعیت را به عنوان شرایط هشدار در نظر بگیرد. منطق مربوط به فعال کردن هشدار و ارسال وضعیت آن از طریق MQTT در ماژول مدیریت حسگرها و سیستم هشدار انجام می‌شود.

برای تشخیص حرکت از ماژول PIR استفاده شده است که خروجی دیجیتال آن به پایه مشخص شده در ESP32 متصل شده است. در زمان راه اندازی، پایه مربوط به PIR به عنوان ورودی تنظیم شده و وضعیت فعال بودن قابلیت تشخیص حرکت نیز از حافظه دائمی بازیابی می شود تا تنظیم انتخاب شده توسط کاربر پس از راه اندازی مجدد دستگاه حفظ شود.

void setupPIR()

{

pinMode(PIR_PIN, INPUT);

motionDetectionEnabled = loadMotionDetection();

if (motionDetectionEnabled)

{

Serial.println("Motion detection restored to ON");

}

}

int readPIR()

{

int input = digitalRead(PIR_PIN);

if (input == HIGH)

{

return 1;

}

return 0;

}

پس از راه اندازی، وضعیت خروجی PIR توسط تابع readPIR() بررسی می شود. در این تابع، مقدار HIGH به عنوان تشخیص حرکت و مقدار LOW به عنوان عدم تشخیص حرکت در نظر گرفته شده است.

به منظور مدیریت وضعیت قابلیت تشخیص حرکت، دو متغیر motionDetectionEnabled و motionDetectionTriggered در Firmware تعریف شده اند که متغیر نخست وضعیت فعال یا غیرفعال بودن قابلیت تشخیص حرکت را مشخص کرده و متغیر دوم وضعیت تحریک شدن سیستم در نتیجه تشخیص حرکت را نگهداری می کند. فعال و غیرفعال کردن این قابلیت نیز از طریق توابع مربوطه انجام شده و علاوه بر تغییر وضعیت داخلی، تنظیم جدید در حافظه ذخیره می شود تا در راه اندازی بعدی نیز قابل بازیابی باشد. به صورت مشابه، برای غیرفعال کردن قابلیت تشخیص حرکت، وضعیت داخلی تغییر کرده و مقدار جدید در حافظه ذخیره می‌شود. در نتیجه، وضعیت تشخیص حرکت تنها در صورتی می تواند موجب ایجاد هشدار شود که مقدار motionDetectionEnabled فعال باشد و در صورت شناسایی حرکت، وضعیت سیستم توسط ماژول مدیریت حسگرها پردازش و در صورت نیاز از طریق MQTT به داشبورد اعلام خواهد شد. جزئیات پیاده‌سازی این بخش در فایل src/PIR/pir.cpp قرار دارد.

### 4-2-2- پیاده سازی سیستم هشدار صوتی

برای ایجاد هشدار صوتی از یک Active Buzzer استفاده شده است که با منطق Active-Low کنترل می‌شود؛ به این معنی که قرار گرفتن پایه خروجی در سطح منطقی LOW باعث فعال شدن بازر و قرار گرفتن آن در سطح HIGH موجب غیرفعال شدن آن می‌شود. در زمان راه‌اندازی Firmware، پایه بازر به عنوان خروجی تنظیم شده و برای جلوگیری از فعال شدن ناخواسته بازر، وضعیت آن در حالت خاموش قرار می گیرد.

void setupBuzzer()

{

pinMode(BUZZER_PIN, OUTPUT);

stopAlarm();

}

void startAlarm()

{

alarmActive = true;

buzzerOn = true;

lastBuzzerToggle = millis();

digitalWrite(BUZZER_PIN, LOW);

}

void stopAlarm()

{

alarmActive = false;

buzzerOn = false;

digitalWrite(BUZZER_PIN, HIGH);

}

تابع startAlarm() وظیفه فعال کردن وضعیت هشدار را بر عهده دارد و با توجه به Active-Low بودن بازر، پایه مربوطه را در سطح LOW قرار می دهد، در حالی که تابع stopAlarm() با قرار دادن پایه در سطح HIGH بازر را غیرفعال می کند. از آنجا که هشدار صوتی سامانه به صورت پیوسته فعال نمی شود و برای ایجاد الگوی هشدار، بازر باید در بازه های زمانی مشخص روشن و خاموش شود، تابع updateAlarm() در حلقه اصلی Firmware فراخوانی می شود و بر اساس وضعیت زمانی سیستم، خروجی بازر را تغییر می دهد. در نتیجه، در صورت فعال بودن هشدار، بازر مطابق چرخه زمانی تعریف شده فعال و غیرفعال شده و در صورت پایان شرایط هشدار، به حالت خاموش باز می گردد. جزئیات کامل پیاده سازی سیستم هشدار صوتی در فایل src/Alarm/alarm.cpp قرار دارد.

## 4-3- پیاده سازی سیستم ارتباط رادیویی RF

یکی از قابلیت های اصلی سامانه، امکان دریافت، ذخیره سازی و بازپخش سیگنال های رادیویی RF است که با هدف فراهم کردن امکان کنترل تجهیزات الکتریکی مجهز به کنترل از راه دور در این پروژه پیاده سازی شده است. در طراحی انجام شده، سیستم RF از دو باند فرکانسی ۳۱۵ و ۴۳۳ مگاهرتز پشتیبانی می کند و برای هر یک از این باند ها یک مسیر مستقل برای دریافت و ارسال سیگنال در نظر گرفته شده است. از آنجا که گیرنده ها و فرستنده های مورد استفاده به صورت تک فرکانس عمل می کنند، برای مدیریت هر باند یک نمونه مستقل از کلاس RCSwitch در Firmware ایجاد شده است و بدین ترتیب سیستم می تواند سیگنال های دو باند را به صورت مستقل دریافت و بازپخش کند. مدیریت ارتباط با ماژول های RF نیز با استفاده از کتابخانه RCSwitch انجام شده است که امکان دریافت و ارسال کد های رایج تجهیزات RF را در اختیار Firmware قرار می دهد.

فرایند راه اندازی سیستم RF در تابع setupRF() انجام می شود و در این مرحله گیرنده و فرستنده مربوط به هر دو باند فعال می شوند. در نتیجه، پس از اجرای این تابع، هر دو گیرنده برای دریافت سیگنال و هر دو فرستنده برای ارسال سیگنال آماده خواهند بود. پایه های مورد استفاده برای این تجهیزات نیز در فایل پیکربندی پروژه تعریف شده اند تا نگاشت پایه ها از منطق اصلی برنامه جدا باشد و در صورت تغییر مدار سخت افزاری، نیاز به تغییر بخش های مختلف Firmware وجود نداشته باشد.

void setupRF()

{

rfSwitch433.enableReceive(RF_RX_433_PIN);

rfSwitch433.enableTransmit(RF_TX_433_PIN);

rfSwitch315.enableReceive(RF_RX_315_PIN);

rfSwitch315.enableTransmit(RF_TX_315_PIN);

{

برای نگهداری اطلاعات سیگنال های دریافت شده، ساختاری با نام RFSignal تعریف شده است که پارامتر های اصلی موردنیاز برای شناسایی، ذخیره و بازپخش سیگنال را در خود نگهداری می کند. در این ساختار، متغیر name نام اختصاص داده شده به سیگنال، code کد دریافت شده، bits تعداد بیت های سیگنال، protocol شماره پروتکل تشخیص داده شده، pulse طول پالس و band باند فرکانسی سیگنال را مشخص می کند. اطلاعات سیگنال های دریافت شده در آرایه signals نگهداری می شوند و تعداد عناصر معتبر این آرایه نیز توسط متغیر signalCount مشخص می شود. استفاده از این ساختار باعث شده است اطلاعات مربوط به هر سیگنال به صورت یک مجموعه منسجم نگهداری شود و عملیات جست و جو، حذف، ذخیره سازی و بازپخش آن ساده تر انجام گیرد.

RFSignal signals[MAX_SIGNALS];

size_t signalCount = 0;

struct RFSignal

{

String name;

uint32_t code;

uint16_t bits;

uint16_t protocol;

uint16_t pulse;

uint16_t band;

};

### 4-3-1- دریافت و ذخیره سازی سیگنال RF

فرایند دریافت سیگنال توسط تابع readRFSignal() انجام می شود. این تابع، وضعیت گیرنده های ۳۱۵ و ۴۳۳ مگاهرتز را بررسی کرده و در صورت دریافت سیگنال، گیرنده ای که سیگنال را دریافت کرده است شناسایی می کند. پس از شناسایی گیرنده فعال، پارامتر های سیگنال از طریق API کتابخانه RCSwitch استخراج شده و در صورت معتبر بودن داده، اطلاعات مربوط به سیگنال در اولین موقعیت آزاد آرایه signals قرار می گیرد. پس از پایان پردازش نیز گیرنده به وضعیت مناسب بازگردانده می شود تا امکان دریافت سیگنال بعدی فراهم باشد.

مدیریت کلی فرایند دریافت و ذخیره سازی توسط تابع handleRFReceive() انجام می شود؛ به این صورت که ابتدا وضعیت سیستم از نظر فعال بودن حالت دریافت بررسی شده و پس از دریافت موفق سیگنال، حالت دریافت غیرفعال شده و اطلاعات به دست آمده برای ذخیره سازی دائمی در اختیار بخش مدیریت حافظه قرار می گیرد. بنابراین، دریافت سیگنال و ذخیره سازی آن به صورت دو مرحله مجزا انجام شده است که این موضوع باعث تفکیک مناسب مسئولیت ها در ساختار Firmware می‌شود. جزئیات کامل پیاده سازی این بخش در فایل های src/RF/receiver.cpp و src/RF/general.cpp قابل مشاهده است.

### 4-3-2- بازپخش و مدیریت سیگنال RF

برای بازپخش سیگنال های ذخیره شده، تابع transmitRFSignal() مورد استفاده قرار می گیرد. در این فرایند ابتدا وجود سیگنال موردنظر و معتبر بودن پارامتر های ذخیره شده بررسی شده و سپس بر اساس مقدار band، فرستنده مناسب انتخاب می شود. پس از انتخاب فرستنده، پروتکل و طول پالس ذخیره شده به آن اختصاص داده شده و در نهایت کد و تعداد بیت های سیگنال برای ارسال در اختیار کتابخانه RCSwitch قرار می گیرد. به این ترتیب، کاربر هنگام ارسال مجدد یک سیگنال تنها کافی است نام آن را مشخص کند و انتخاب فرستنده و پارامتر های مورد نیاز توسط Firmware انجام می شود.

به منظور دسترسی به سیگنال های ذخیره شده، تابع findRFSignalByName() برای جست و جوی سیگنال بر اساس نام آن پیاده سازی شده است. این تابع عناصر معتبر آرایه signals را از ابتدا تا انتها بررسی می کند و در صورت پیدا شدن سیگنالی با نام موردنظر، مکان آن را بر می گرداند؛ در صورتی که سیگنال موردنظر در حافظه وجود نداشته باشد، مقدار nullptr بازگردانده می شود.

RFSignal *findRFSignalByName(const String &name)

{

for (size_t i = 0; i < signalCount; i++)

{

if (signals[i].name == name)

{

return &signals[i];

}

}

return nullptr;

}

برای حذف یک سیگنال نیز ابتدا با استفاده از همین تابع وجود سیگنال بررسی می شود و پس از پیدا شدن آن، موقعیت سیگنال در آرایه مشخص می شود. سپس عناصر قرارگرفته پس از آن یک موقعیت به سمت چپ منتقل می شوند تا فضای خالی ایجاد شده حذف شود و مقدار signalCount نیز یک واحد کاهش پیدا می‌کند. در ادامه، آرایه جدید در حافظه دائمی ذخیره می‌شود.

RFSignal *signal = findRFSignalByName(name);

if (signal == nullptr)

{

Serial.println("RF signal not found");

return;

}

size_t index = signal - signals;

for (size_t i = index; i + 1 < signalCount; i++)

{

signals[i] = signals[i + 1];

}

signalCount--;

if (saveRFSignals())

{

Serial.print("Deleted RF signal: ");

Serial.println(name);

}

else

{

loadRFSignals();

Serial.println("Failed to delete RF signal");

}

همچنین برای نمایش فهرست سیگنال های ذخیره شده، تابع listRFSignals() پیاده سازی شده است که اطلاعات سیگنال ها را شامل نام، باند فرکانسی، کد، تعداد بیت و پروتکل استخراج کرده و علاوه بر نمایش در Serial Monitor، اطلاعات را در قالب JSON از طریق MQTT منتشر می کند. اطلاعات این بخش از طریق Topic مربوط به RF/list منتشر می شود.

جزئیات کامل پیاده سازی این بخش در فایل src/RF/transmitter.cpp و src/RF.general.cpp قابل مشاهده است.

### 4-3-3- منطق کلی دریافت و ارسال RF

فرایند دریافت سیگنال در سامانه به صورت زیر است:

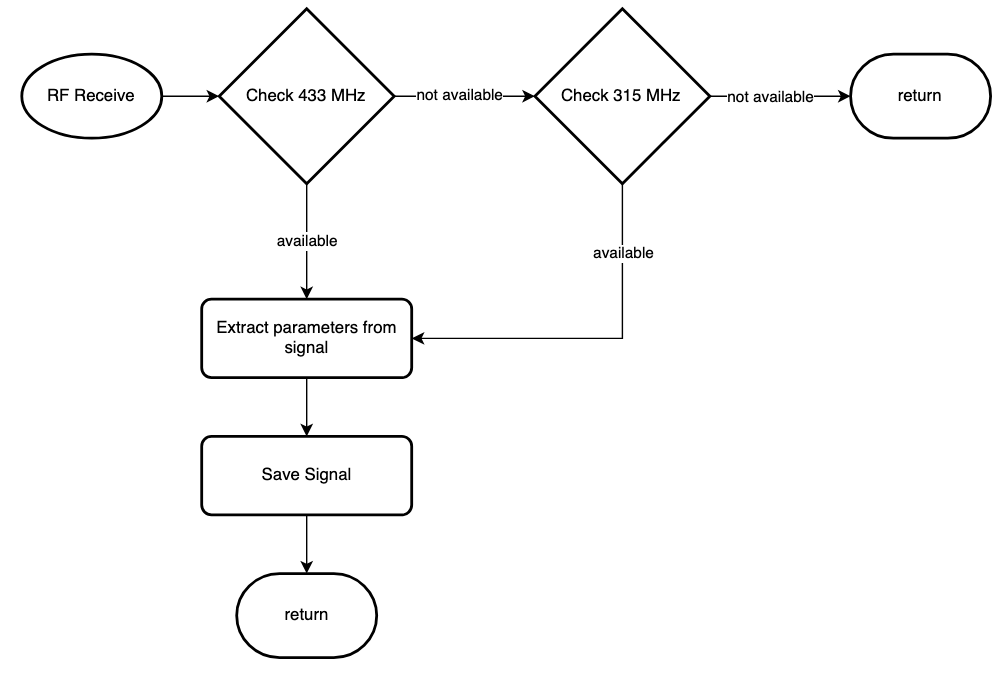
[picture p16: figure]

###### شکل (4-1) فرایند دریافت سیگنال RF

فرایند ارسال سیگنال در سامانه به صورت زیر است:

###### شکل (4-2) فرایند ارسال سیگنال RF

## 4-4- پیاده سازی سیستم مادون قرمز IR

یکی دیگر از قابلیت های اصلی سامانه، امکان دریافت، ذخیره سازی و بازپخش فرمان های مادون قرمز است که با هدف فراهم کردن امکان کنترل تجهیزاتی مانند تلویزیون، سیستم های تهویه، پخش کننده ها و سایر تجهیزات خانگی مجهز به کنترل از راه دور مادون قرمز در پروژه پیاده سازی شده است. در این بخش، یک گیرنده مادون قرمز برای دریافت سیگنال های ارسالی از کنترل ها و چهار LED مادون قرمز برای بازپخش سیگنال های ذخیره شده مورد استفاده قرار گرفته است. پردازش، تشخیص پروتکل و ارسال سیگنال های IR توسط کتابخانه IRremoteESP8266 انجام می شود و ساختار نرم افزاری سیستم به گونه ای طراحی شده است که علاوه بر سیگنال های قابل Decode، امکان ذخیره و بازپخش سیگنال های ناشناخته به صورت داده خام نیز وجود داشته باشد.

برای مدیریت بخش دریافت و ارسال، یک شی از کلاس IRrecv و یک شی از کلاس IRsend ایجاد شده است که به ترتیب مسئول دریافت و Decode کردن سیگنال های مادون قرمز و آماده سازی و ارسال مجدد آنها هستند. راه‌اندازی این دو بخش در تابع setupIR() انجام می‌شود. با اجرای این تابع، گیرنده IR برای دریافت سیگنال آماده شده و بخش ارسال نیز راه اندازی می شود تا در ادامه Firmware بتواند بر اساس فرمان های دریافت شده، عملیات دریافت یا ارسال سیگنال را انجام دهد.

IRrecv irReceiver(IR_RX_PIN);

IRsend irTransmitter(IR_TX_PIN);

void setupIR()

{

irReceiver.enableIRIn();

irTransmitter.begin();

}

برای نگهداری اطلاعات سیگنال های دریافت شده، ساختاری با نام IRSignal تعریف شده است که علاوه بر اطلاعات Decode شده، داده خام سیگنال را نیز در خود نگهداری می‌کند. در این ساختار، متغیر name نام اختصاص داده شده به سیگنال، protocol نوع پروتکل تشخیص داده شده، value مقدار Decode شده، bits تعداد بیت های سیگنال، rawLength تعداد نمونه های داده خام و rawData آرایه مربوط به داده خام سیگنال را نگهداری می کند. استفاده همزمان از اطلاعات Decode شده و داده خام اهمیت دارد، زیرا همه سیگنال های مادون قرمز الزاما توسط کتابخانه به یک پروتکل شناخته شده قابل تشخیص نیستند و در چنین شرایطی برای بازپخش صحیح سیگنال باید اطلاعات خام آن حفظ شود. سیگنال های دریافت شده در آرایه irSignals نگهداری شده و تعداد سیگنال های معتبر نیز توسط متغیر irSignalCount مشخص می شود.

برای ذخیره اطلاعات سیگنال های مادون قرمز، ساختار IRSignal تعریف شده است:

IRSignal irSignals[MAX_SIGNALS];

size_t irSignalCount = 0;

struct IRSignal

{

String name;

decode_type_t protocol;

uint64_t value;

uint16_t bits;

uint16_t rawLength;

uint16_t rawData[MAX_IR_RAW_LENGTH];

};

### 4-4-1- دریافت و ذخیره سازی سیگنال IR

فرایند دریافت و Decode سیگنال مادون قرمز توسط تابع readIRSignal() انجام می شود. در این فرایند ابتدا یک ساختار decode_results برای نگهداری نتیجه دریافت و Decode ایجاد شده و گیرنده IR بررسی می‌کند که آیا سیگنال جدیدی دریافت شده است یا خیر. پس از دریافت سیگنال، پارامترهای مربوط به وضعیت دریافت از جمله overflow و طول داده خام بررسی می شوند تا از معتبر بودن اطلاعات اطمینان حاصل شود. در صورت معتبر بودن داده، یک موقعیت آزاد در آرایه irSignals اختصاص داده شده و اطلاعات مربوط به پروتکل، مقدار Decode شده، تعداد بیت ها و داده خام سیگنال در ساختار مربوطه ذخیره می شوند.

یکی از نکات مهم در این پیاده سازی، ذخیره سازی داده خام در کنار اطلاعات Decode شده است؛ زیرا ممکن است پروتکل یک کنترل از راه دور توسط کتابخانه IRremoteESP8266 شناسایی نشود، اما شکل موج دریافت شده همچنان قابل بازپخش باشد. بنابراین، نگهداری آرایه rawData باعث می‌شود سامانه محدود به پروتکل های شناخته شده نباشد و بتواند در صورت ناشناخته بودن پروتکل نیز سیگنال دریافت شده را در قالب خام ذخیره کند.

مدیریت کلی فرایند دریافت توسط تابع handleIRReceive() انجام می‌شود. این تابع ابتدا بررسی می کند که سیستم در حالت دریافت IR قرار داشته باشد و در صورت دریافت موفق سیگنال، حالت دریافت را غیرفعال کرده و اطلاعات به دست آمده را برای ذخیره سازی دائمی در اختیار بخش مدیریت حافظه قرار می دهد. در نتیجه، دریافت یک سیگنال پس از اجرای فرمان مربوطه تنها تا زمان دریافت اولین سیگنال معتبر ادامه پیدا می کند و پس از ذخیره اطلاعات، سیستم به حالت عادی اجرای Firmware باز می گردد.

جزئیات پیاده سازی این بخش در فایل های src/IR/receiver.cpp و src/IR/general.cpp قابل مشاهده است.

### 4-4-2- بازپخش و مدیریت سیگنال IR

برای بازپخش سیگنال های ذخیره شده، تابع transmitIRSignal() مورد استفاده قرار می گیرد. در ابتدای این فرایند وجود سیگنال موردنظر و معتبر بودن اطلاعات آن بررسی شده و سپس بر اساس مقدار protocol، روش مناسب برای ارسال انتخاب می شود. در صورتی که پروتکل سیگنال توسط Firmware پشتیبانی شود، اطلاعات Decode شده با استفاده از روش ارسال مربوط به همان پروتکل منتقل می شود و در صورتی که پروتکل ناشناخته باشد یا امکان ارسال آن به صورت Decode شده وجود نداشته باشد، داده خام ذخیره شده در rawData با فرکانس حامل ۳۸ کیلوهرتز بازپخش می‌شود.

در نسخه فعلی Firmware، پروتکل های رایج NEC، SONY، SAMSUNG و PANASONIC پشتیبانی می شوند و برای سایر سیگنال ها، در صورت وجود داده خام معتبر، روش ارسال خام مورد استفاده قرار می گیرد. این روش باعث می شود قابلیت بازپخش سامانه تنها به پروتکل های شناخته شده محدود نباشد و امکان ذخیره و استفاده مجدد از برخی سیگنال هایی که توسط کتابخانه قابل Decode نیستند نیز فراهم شود.

برای پیدا کردن سیگنال بر اساس نام، تابع findIRSignalByName() پیاده سازی شده است. این تابع عناصر معتبر آرایه irSignals را از ابتدا تا انتها بررسی می کند و در صورت پیدا شدن سیگنالی با نام موردنظر، مکان آن را بر می گرداند؛ در صورتی که سیگنال موردنظر در حافظه وجود نداشته باشد، مقدار nullptr بازگردانده می شود.

IRSignal *findIRSignalByName(const String &name)

{

for (size_t i = 0; i < irSignalCount; i++)

{

if (irSignals[i].name == name)

{

return &irSignals[i];

}

}

return nullptr;

}

برای حذف یک سیگنال نیز با استفاده از همین تابع وجود سیگنال بررسی می شود و پس از پیدا شدن آن، موقعیت سیگنال در آرایه مشخص می شود. سپس عناصر قرارگرفته پس از آن یک موقعیت به سمت چپ منتقل می شوند تا فضای خالی ایجاد شده حذف شود و مقدار irSignalCount نیز یک واحد کاهش پیدا می‌کند. در ادامه، آرایه جدید در حافظه دائمی ذخیره می‌شود.

IRSignal *signal = findIRSignalByName(name);

if (signal == nullptr)

{

Serial.println("IR signal not found");

return;

}

size_t index = signal - irSignals;

for (size_t i = index; i + 1 < irSignalCount; i++)

{

irSignals[i] = irSignals[i + 1];

}

irSignalCount--;

if (saveIRSignals())

{

Serial.print("Deleted IR signal: ");

Serial.println(name);

}

else

{

loadIRSignals();

Serial.println("Failed to delete IR signal");

}

همچنین برای نمایش فهرست سیگنال های ذخیره شده، تابع listIRSignals() در نظر گرفته شده است که اطلاعات هر سیگنال شامل نام، پروتکل، تعداد بیت و طول داده خام را استخراج کرده و علاوه بر نمایش در Serial Monitor، آنها را در قالب یک شی JSON آماده کرده و از طریق MQTT منتشر می‌کند. اطلاعات فهرست سیگنال ها از طریق Topic مربوط به IR/list در اختیار داشبورد قرار می گیرد و در نتیجه کاربر می تواند بدون دسترسی مستقیم به حافظه دستگاه، سیگنال های ذخیره شده را مشاهده و مدیریت کند.

جزئیات پیاده سازی در فایل src/IR/transmitter.cpp و src/IR/general.cpp قابل مشاهده است.

### 4-4-3- منطق کلی دریافت و ارسال IR

فرایند دریافت سیگنال در سامانه به صورت زیر است:

###### شکل (4-1) فرایند دریافت سیگنال IR

فرایند ارسال سیگنال در سامانه به صورت زیر است:

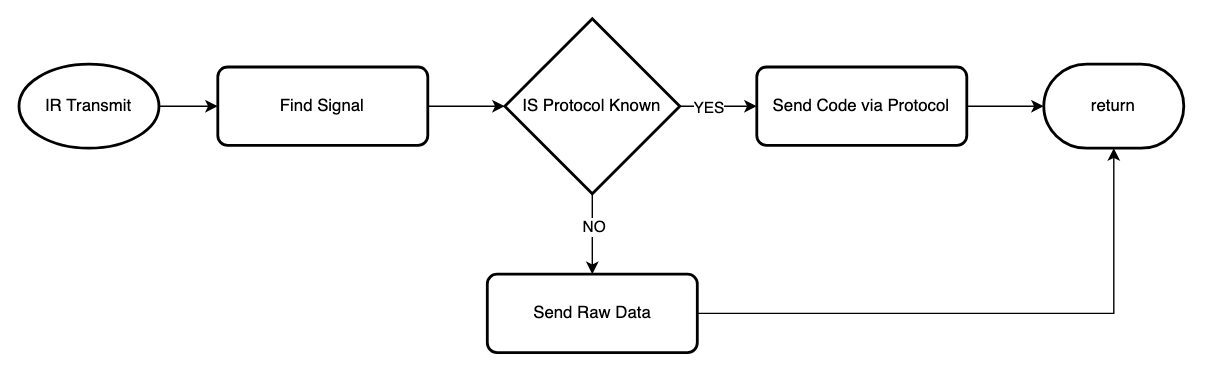
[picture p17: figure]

###### شکل (4-2) فرایند ارسال سیگنال IR

## 4-5- پیاده سازی ارتباط WiFi و MQTT

به منظور ایجاد ارتباط میان دستگاه و زیرساخت نرم افزاری سامانه، از دو فناوری WiFi و MQTT استفاده شده است که در این ساختار، ارتباط WiFi وظیفه اتصال ESP32 به شبکه محلی و فراهم کردن مسیر ارتباطی میان دستگاه و MQTT Broker را بر عهده دارد و پروتکل MQTT نیز برای تبادل اطلاعات حسگرها، وضعیت سیستم و فرمان های کنترلی میان ESP32، Broker و داشبورد تحت وب مورد استفاده قرار می گیرد. پیاده سازی این بخش به گونه ای انجام شده است که قطع یا اختلال موقت در ارتباط شبکه باعث توقف عملکرد بخش های محلی سیستم نشده و Firmware بتواند در زمان مناسب برای برقراری مجدد ارتباط تلاش کند.
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

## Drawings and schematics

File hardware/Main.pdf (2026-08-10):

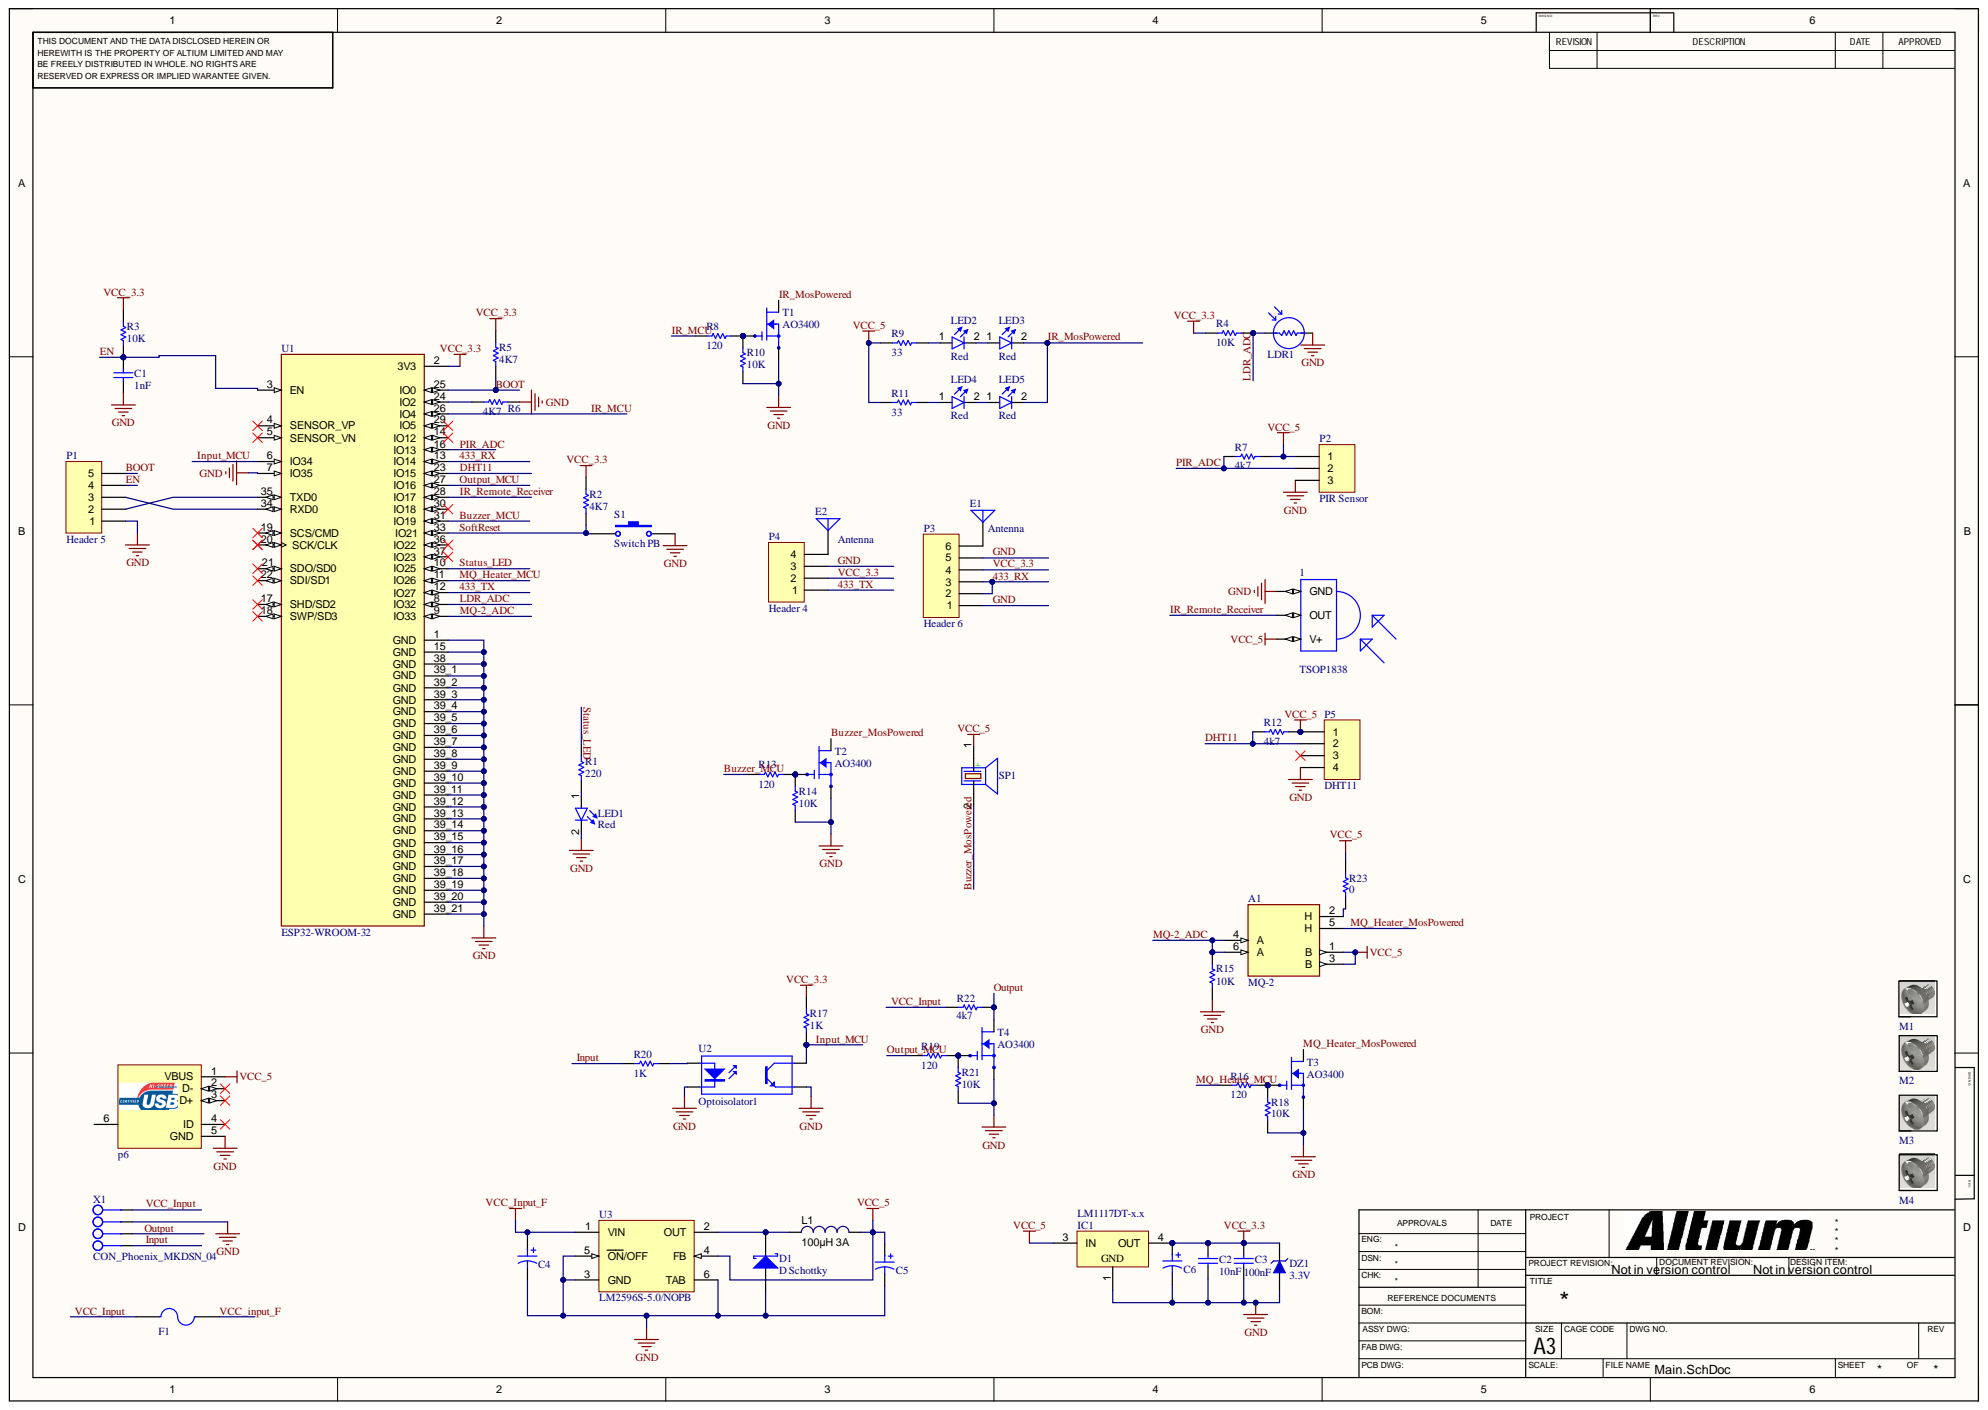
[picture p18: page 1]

THIS DOCUM ENT AND THE DATA DISCLOS ED HEREIN OR HERE WITH IS THE PROP ERT Y OF A LTIUM LIMIT ED AND M AY B E FRE E LY DIS TRIBUT ED IN WHOL E. NO RIGHT S ARE RE S ERV ED OR E X PRE S S OR IM P LIED W ARANT E E GIV EN. | | R E V I S I ON | D E S C R I PT I ON | D AT E | A P P R OVE D

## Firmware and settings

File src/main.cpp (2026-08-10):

#include <config.h>
#include <Provisioning/provisioning.h>
#include <Serial/serial.h>
#include <Sensors/sensors.h>

String receiveName = "";
bool receivingRF = false;
bool receivingIR = false;

void handleMqttCommand(const String &command)
{
    handleSerialCommand(command);
}

void setup()
{
    Serial.begin(115200);
    delay(200);

    loadProvisioningConfig();
    startConfigAP();

    setupSensors();
    setupMQTT(handleMqttCommand);
    printHelp();
}

void loop()
{
    handleSerial();
    handleMQTT();
    handleConfigAP();
    handleSensors();
}

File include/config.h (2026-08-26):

#ifndef CONFIG_H
#define CONFIG_H

#include <Arduino.h>

const char PROVISIONING_FILE_PATH[] = "/provisioning.json";
const char PROVISIONING_AP_SSID[] = "Intelligence-Setup";
const char PROVISIONING_AP_PASSWORD[] = "12345678";

const char RF_FILE_PATH[] = "/rf_signals.json";
const char IR_FILE_PATH[] = "/ir_signals.json";
const char SETTINGS_FILE_PATH[] = "/settings.json";
const size_t MAX_SIGNALS = 20;
const size_t MAX_IR_RAW_LENGTH = 200;

const char WIFI_SSID[] = "YOUR_WIFI_SSID";
const char WIFI_PASSWORD[] = "YOUR_WIFI_PASSWORD";

const char MQTT_HOST[] = "192.168.1.10";
const uint16_t MQTT_PORT = 1883;
const char MQTT_CLIENT_ID[] = "esp32-intelligence";
const char MQTT_USER[] = "";
const char MQTT_PASSWORD[] = "";
const char MQTT_BASE_TOPIC[] = "homeintelligence";

const char MQTT_LDR_TOPIC[] = "sensor/LDR";
const char MQTT_TEMP_TOPIC[] = "sensor/TEMP";
const char MQTT_HUM_TOPIC[] = "sensor/HUM";
const char MQTT_PIR_TOPIC[] = "sensor/PIR";
const char MQTT_MQ2_TOPIC[] = "sensor/MQ2";
const char MQTT_ALARM_TOPIC[] = "alarm";
const char MQTT_COMMAND_TOPIC[] = "command";
const char MQTT_RF_SIGNAL_TOPIC[] = "RF/list";
const char MQTT_IR_SIGNAL_TOPIC[] = "IR/list";

extern String receiveName;
extern bool receivingRF;
extern bool receivingIR;

#define MQTT_RECONNECT_INTERVAL 1000

#define WIFI_PROVISIONING_FALLBACK_MS 30000

#define LDR_PIN 34

#define MQ2_PIN 35

#define DHT_PIN 33
#define DHT_TYPE DHT11

#define PIR_PIN 13

#define BUZZER_PIN 32
#define STATUS_LED_PIN 12

#define RF_RX_433_PIN 27
#define RF_TX_433_PIN 26
#define RF_RX_315_PIN 4
#define RF_TX_315_PIN 5

#define IR_RX_PIN 14
#define IR_TX_PIN 25

#define SENSOR_READ_INTERVAL 10000
#define MQ2_PREHEAT_DURATION 300000
#define MQ2_READ_INTERVAL 15000
#define MQ2_THRESHOLD 700

#define BUZZER_DUTY_CYCLE_INTERVAL 2000

#define STATUS_LED_ON 1000
#define STATUS_LED_OFF 5000
#define STATUS_LED_PULSE 500

#endif

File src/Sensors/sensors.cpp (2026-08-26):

#include <Sensors/sensors.h>

unsigned long lastSensorPrint = 0;
unsigned long nextMQ2ReadAt = 0;

void setupSensors()
{
    setupMQ2();
    setupDHT();
    setupPIR();
    setupBuzzer();
    setupRF();
    setupIR();
    setupLDR();
    nextMQ2ReadAt = millis() + MQ2_PREHEAT_DURATION;
    loadRFSignals();
    loadIRSignals();
    setupStatusLED();
}

void printMQ2()
{
    unsigned long now = millis();

    if (now < nextMQ2ReadAt)
    {
        return;
    }

    int gas = readMQ2();
    if (checkThreshold(gas))
    {
        Serial.println("MQ2 threshold exceeded!");
        publishMQTT(MQTT_ALARM_TOPIC, "MQ2 threshold exceeded!");
        startAlarm();
    }
    Serial.print("MQ2=");
    Serial.println(gas);
    publishMQTT(MQTT_MQ2_TOPIC, String(gas));

    nextMQ2ReadAt += MQ2_READ_INTERVAL;
    if (now > nextMQ2ReadAt)
    {
        nextMQ2ReadAt = now + MQ2_READ_INTERVAL;
    }
}

void printSensors()
{
    if (receivingIR || receivingRF)
    {
        return;
    }

    if (millis() - lastSensorPrint < SENSOR_READ_INTERVAL)
    {
        printMQ2();
        return;
    }

    Serial.println(".............................");
    int LDR = readLDR();
    Serial.print("LDR=");
    Serial.println(LDR);
    publishMQTT(MQTT_LDR_TOPIC, String(LDR));
    float temp = readTemperature();
    Serial.print("TEMP=");
    Serial.println(temp);
    publishMQTT(MQTT_TEMP_TOPIC, isnan(temp) ? "0" : String(temp, 1));
    float humidity = readHumidity();
    Serial.print("HUM=");
    Serial.println(humidity);
    publishMQTT(MQTT_HUM_TOPIC, isnan(humidity) ? "0" : String(humidity, 1));
    int motion = readPIR();
    Serial.print("PIR=");
    Serial.println(motion);
    publishMQTT(MQTT_PIR_TOPIC, String(motion));
    Serial.println(".............................");

    lastSensorPrint = millis();
    printMQ2();
}

void handleSensors()
{
    handleRFReceive(receivingRF, receiveName);
    handleIRReceive(receivingIR, receiveName);
    updateAlarm();
    updateStatusLED();
    updatePulseLED();
    checkMotionDetection();
    printSensors();
}

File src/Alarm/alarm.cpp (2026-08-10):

#include <Alarm/alarm.h>

bool alarmActive = false;
bool buzzerOn = false;
unsigned long lastBuzzerToggle = 0;

void setupBuzzer()
{
    pinMode(BUZZER_PIN, OUTPUT);
    stopAlarm();
}

void startAlarm()
{
    alarmActive = true;
    buzzerOn = true;
    lastBuzzerToggle = millis();
    digitalWrite(BUZZER_PIN, LOW);
}

void stopAlarm()
{
    alarmActive = false;
    buzzerOn = false;
    digitalWrite(BUZZER_PIN, HIGH);
}

void updateAlarm()
{
    if (!alarmActive)
    {
        return;
    }

    if (millis() - lastBuzzerToggle < BUZZER_DUTY_CYCLE_INTERVAL)
    {
        return;
    }

    buzzerOn = !buzzerOn;
    lastBuzzerToggle = millis();
    digitalWrite(BUZZER_PIN, buzzerOn ? LOW : HIGH);
}

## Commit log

2026-07-01 clean the code and fix bugs
    [general.cpp, main.cpp, memory.cpp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]
2026-07-22 fix the bug of RF receiver
    [receiver.cpp, serial.cpp]
2026-07-22 fix the provisioning bug
    [config.h, mqtt.cpp]
2026-07-22 fix the motion detection bug
    [pir.cpp]
2026-08-10 add status LED
2026-08-10 add hardware schematic
    [Main.SchDoc, PCB1.PcbDoc]
2026-08-26 add document and fix bugs
    [config.h, general.cpp, memory.cpp]
